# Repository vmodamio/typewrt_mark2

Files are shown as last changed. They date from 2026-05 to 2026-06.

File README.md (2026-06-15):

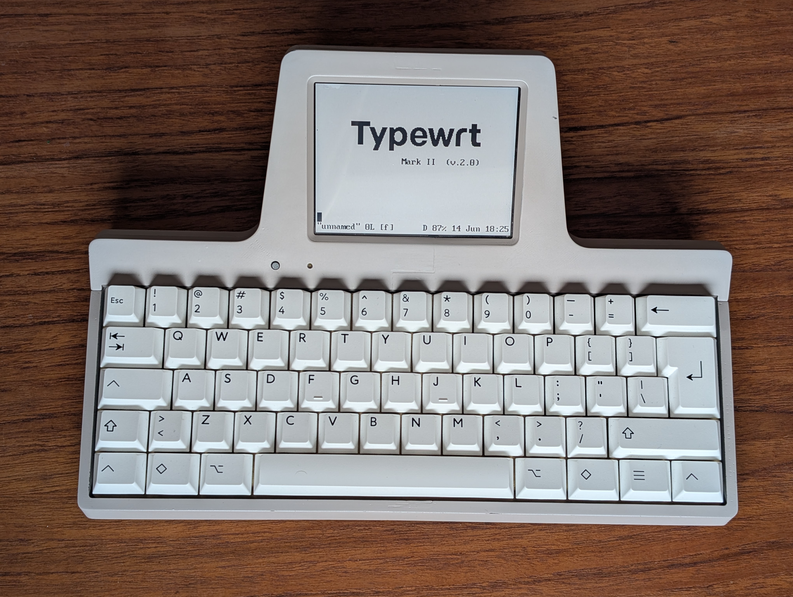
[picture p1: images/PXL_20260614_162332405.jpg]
Typewrt2


# Typewrt Mark II (ver 2.0)

Typewrt is a modern conception of a digital typewriter, designed as an
instrument for creating literary works without the need of further devices or
software. 
The idea revolves around a mechanical feeling, and it is designed with the
following key aspects:
1) Output: A reflective memory-in-pixel monochrome LCD from SHARP. This is a
4.4" display with a todays low resolution (320x240, QVGA). This resolution is 
enough to produce sharp glyphs using VGA font 8x16 bitmaps. It allows for 15
lines with 40 characters. The readability is exceptional both indoors and
outdoors. Because of the resolution and the ability to perform partial
refreshes, it updates very fast. 

2) Input: A mechanical keyboard with high quality switches and thick PBT
keycaps, arranged in a 60% layout. Mounted in a sturdy brass plate and a custom
made PCB. 
4) Power: Typewrt doesn't produce light. It doesn't stress the eyes. It doesn't
produce heat when you write on the lap. And it does not need a charger around.
The SHARP display is ultra low power. As it does the keyboard and the main
board. 
3) Process: The core of the device, and the main departure from a typewriter or 
a simple drafting device. Typewrt is an embedded vi text editor. It allows to
navigate through the document or documents very efficiently. Manipulate text
with any complexity, and recursively. Do search and replace, etc. You can even
autocomplete words, or perform fuzzy searches. It works natively with utf-8
encoding, and it can change the keyboard layout on the fly to english, spanish,
italian, french, german, norwegian, turkish and colemak.
5) Ergonomics: The design is meant to be robust and stable. The keyboard height
has been minimized. Cherry profile keycups are used, and the keyboard plane is
tilted by 6 degree.  The display distance and viewing angle is kept large
enough to allow long writing sessions. The display is 35 degree respect to the 
horizontal plane. The keyboard has been silenced as much as possible, so you
have a good peace of mind when typing in public places.  The tactility and
response of the keyboard is very conforting. 
6) Remote sync: The device has LE Bluetooth and allows to copy your files to
your phone consuming very little power, and without needing external networks.

The main difference of Typewrt mark II respect to the first iteration is the
hardware. Typewrt-I was built with a single-board-computer, running a ARM based 
linux from which you could run any program on the terminal. 
Typewrt-II doesn't have a computer. There is no terminal or specific drivers for
the keyboard or the display. Keyboard, display and text processor conform a
unique firmware embedded into a ESP32S3 microprocessor. 
Just one application (a modified vi editor with a simple file browser), running 
in a much more constrained environment. 8 MB of ram memory instead of 0.5 GB in
Typewrt-I. 1 MB firmware on flash memory instead of 0.5GB of linux distribution. 
And still, it performs faster, and consumes much less power. 
The interaction with Typewrt-2 is straight. There is no loggins or shells or
passwords. You press the power button and start writing instant on a blank 
document.

# How to:
Because the esp firmware is a submodule repository, clone this project as 
``` 
git clone --recurse-submodules https://github.com/vmodamio/typewrt_mark2.git 
```
The building process might be a long project. Please dont hesitate to ask if you
find difficulties and/or lack of documentation. 
For flashing the firmware, you need the Espressiff IDF installed in your computer.
You can follow [the instructions here for the v6.0](https://docs.espressif.com/projects/esp-idf/en/v6.0.1/esp32s3/get-started/index.html)
Once installed, from the /firmware/esp folder:
``` 
idf.py build
idf.py flash
```

# Firmware:
The text editor has been forked from the [fantastic nextVi](https://github.com/kyx0r/nextvi) 
text editor by Kyryl Melekhin. The editor, originally a terminal program, has been 
adapted to an embedded firmware using the Espressiff IDF, and it runs under FreeRTOS. 
Regarding functionality, the original right-to-left support, all the syntax highlight and 
filetype code, as well as all shell/terminal related code has been removed. 
The program has been adapted to a non-terminal environment, with a custom
keyboard and display interpretation. Additionally, all the functionality related to
files, paths or filesystem in general, has been derived to a more-dedicated filebrowser. 
The filebrowser is in fact the place where you land with the former quit command. 
A battery, memmory and date/time status has been added, as well as a BLE small protocol 
to transfer files.  And last, an special hard-wrap mechanism has been implemented.  

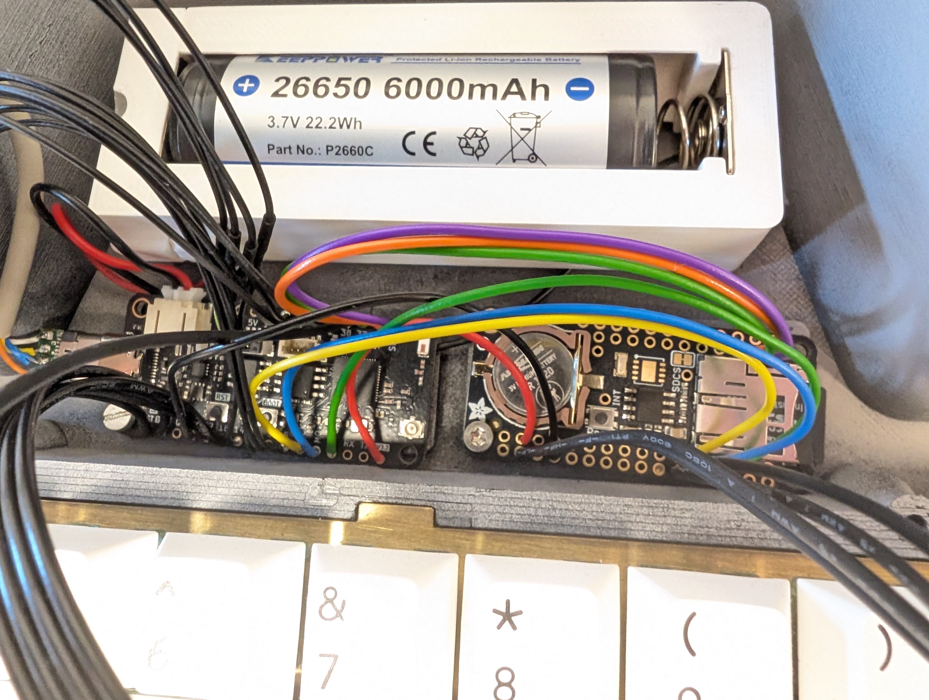
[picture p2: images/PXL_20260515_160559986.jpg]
hardware

# Hardware:
The machine consists on a feather ESP32s3[d] (unexpected maker) and an Adafruit
adalogger RTC+SD card. The Sharp MIP 4.4" display, is mounted in a custom PCB
that has a 5V booster, and a 7555 timer for the vcom signal (both ultra low
power). The keyboard pcb consists barely on an octal latch SN74HC573A that
drives 8 inputs/outputs. In addition, a power button and a yellow led on the 
enclosure, and a usb-c connector on the back. For the connector, a tiny pcb was
made to pull down the CC1 and CC2 lines with 5.1k. It has also a small jumper to
remove the data lines, in case you dont want someone touching your firmware. 

# Power figures:
Typewrt main display, the SHARP MIP, consumes 50 uA when idle, and 600 uA when
refreshing. It is probably the lowest power display ever. This, considering
that, in many writing divices, the display is by far the most power hungry part.
The keyboard on Typewrt mark I was implemented on a low power STM32
microcontroller, working in interrupt mode and sleeping most of the time, and
sending via uart events. Typewrt mark II is just one microcontroller, doing
exactly the same task as for the keyboard, but for the whole firmware. 
The display vcom signal is hardware produced with the timer, so no task is
needed for the display when the system is idle.
Check the power consumption folder for real measurements.
Machine idle is around 1.4 mA, typing costs 38 mA, and deep sleep 340 uA.

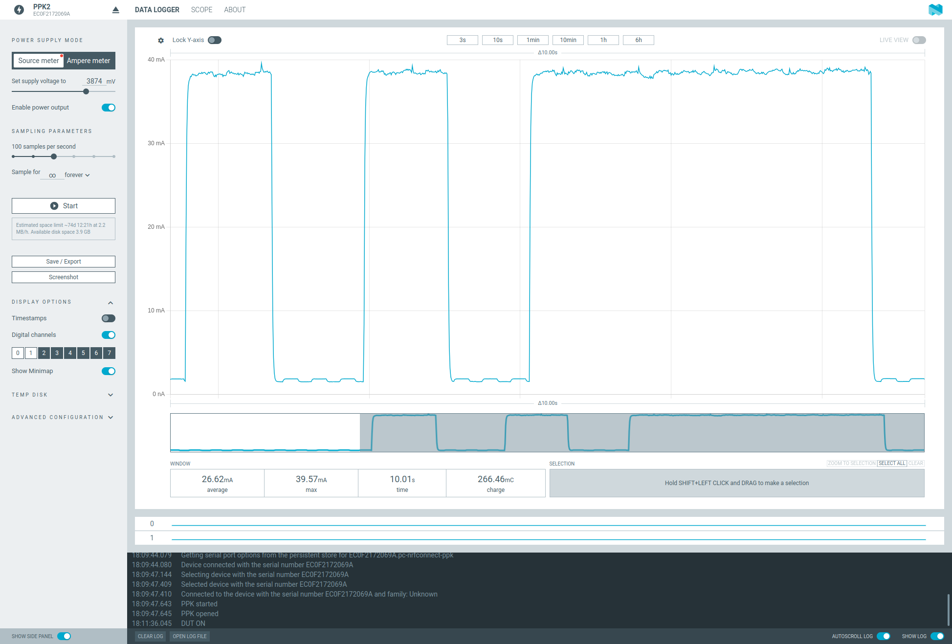
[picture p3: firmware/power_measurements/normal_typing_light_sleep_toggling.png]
power


# Vi at a glance:

Vi is one of the main text editors in unix/linux distributions. Its
functionality is divided into three different modes: insert, nomal and ex mode.
Once you are inside vi, you press "i" to enter insert mode, and you can start
typing in your document. Many people hate vi just because this initial
frustration, akwardness responses of the keyboard when you are not in Insert
mode. This is because vi is very powerful. It has many key bindings, and the
learning curve is somehow step. 

In insert mode, it behaves like the simplest text editor you could imagine. As
far as you dont escape, pressing the Esc key, you basically insert characters
in your text buffer. There are very few but useful key bindings in insert mode
however. Press Ctrl-W to delete your last word. Or Ctrl-N to autocomplete a
word you started typing.  To save your text (to write your buffer into a file),
you escape to enter normal mode, then you type ":" to enter ex mode, and "w
<filename>" to write.

Normal mode is where things get fun. In this mode you dont create text by
typing, but instead you type keybindings to manipulate the text you already
have, or navigate throw the buffer/buffers, copy or paste pieces of text into
the buffer, or different registers, search or replace, delete, and many other
things. This editor paradigm works very nice for coding, among other things,
were you would spend considerable part of your time rearranging pieces of text
or modifying functions or variables. For writing fiction I find it equally
useful.  The navigation, or movements, are the first step departing from your
standard, plain editor. The left, right, up and down cursor movements in vi are
arranged in the main keyboard row as h,j,k,l for left, down, up and right. 
That is the main reason you would't need arrow keys in a vi text editor. 
If you get used to this, you wont miss again the arrow keys.  You can move
forward or backwards by words, paragraphs, programmed marks, entire
documents/buffers.
You can concatenate actions with movements, like delete 5 words backwards, or
find character <character> 3 times, to say, or copy text til mark, or
paste register 1...  Pressing "." in normal mode executes the last instruction
again. For example "dB" to delete backwards  to the begining of a word
(including punctuation). Then pressing "." will continue to delete that way.

# Credits:
The text editor is based on the nextVI project (please refer to the firmware folder).
The VGA font is borrowed from the ZAP group, Australia (Copyright (C) 2004–26, John Zaitseff).
The font used for the splash screen is MomoTrustDisplay-Regular.ttf (Google fonts) 
designed by Type Associates, Copyright 2024 The MoMo Trust Display Project Authors. 

# License:
This project is distributed under GPL3 license. Copyright (C) 2026 Victor Modamio

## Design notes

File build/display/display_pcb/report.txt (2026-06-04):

Plotted to '/home/vik/typewriter/display/pcb/Sharp_display/Sharp_display-F_Cu.gbr'.
Plotted to '/home/vik/typewriter/display/pcb/Sharp_display/Sharp_display-B_Cu.gbr'.
Plotted to '/home/vik/typewriter/display/pcb/Sharp_display/Sharp_display-F_Paste.gbr'.
Plotted to '/home/vik/typewriter/display/pcb/Sharp_display/Sharp_display-B_Paste.gbr'.
Plotted to '/home/vik/typewriter/display/pcb/Sharp_display/Sharp_display-F_Silkscreen.gbr'.
Plotted to '/home/vik/typewriter/display/pcb/Sharp_display/Sharp_display-B_Silkscreen.gbr'.
Plotted to '/home/vik/typewriter/display/pcb/Sharp_display/Sharp_display-F_Mask.gbr'.
Plotted to '/home/vik/typewriter/display/pcb/Sharp_display/Sharp_display-B_Mask.gbr'.
Plotted to '/home/vik/typewriter/display/pcb/Sharp_display/Sharp_display-Edge_Cuts.gbr'.
Created Gerber job file '/home/vik/typewriter/display/pcb/Sharp_display/Sharp_display-job.gbrjob'.
Info: Done.

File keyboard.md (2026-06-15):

Typewrt keyboard is designed from scratch. From the pcb design to the driver
and communication protocol.  It cannot be called "driver" anymore since the
Mark II, as now everything is embedded in a unique firmware. But the concept
remains the same to my first Typewrt vision. In Typewrt 1, a interrupt driven
microcontroller was sending key events via uart, sleeping the rest of the time.
In typewrt 2, the whole firmware is in the same microcontroller, that is
globally sleeping when no key is pressed.

# Matrix and scaning mechanism:
The 60% ISO keyboard layout has 62 keys. The optimal way to arrange them would
be a 8x8 matrix, with only two spares.  Typewrt 2 has this matrix, and it
allowed me to use a very practical multiplexing mechanism to reduce even
further the number of pins used: an octal latch.  This is a small component
with 8 inputs and 8 outputs. You can program the outputs to be insolated
(latched), or to be seeing the inputs. The rows are connected to the outputs
and the columns to the inputs, so the mechanism goes as folow: you input one
high and rest low. This goes so far symmetrically to rows and cols, as the
output is connected to the input. Then you latch the outputs (insolated from
inputs now), and set the inputs...

# Debounce and denonise:
When a key is pressed, the switch contacts will bounce producing an intermitent
connection during few milliseconds, before it settles down. One standard
procedure for avoiding the misleading behaviour is to wait for a safe time
window, and read the status of the switch after. A typical debounce time is 10
to 20 ms. This delay is negligible and your keyboard is perceived as
instantaneous for you.  With this strategy however, the keyboard is not inmune
to noise in the circuit, that could trigger a false key event because of
residual charges in the line,for example. 
For typewrt 2 I opted for a robust debouncing/denoising strategy: using shift
registers.  The basic idea is that the status of a key is scanned several
times, every one millisecond. When te scan reports 8 consecutive and identical
states, that are different to the previous key status, it reports the key event
and changes the key status to the new value.This is maybe one of the pieces of
this project where I havent spare in power consumption, as it demands slightly
more cpu. But at the same time provides a very robust keyboard response, that
delivers key events as fast as possible.

# Keyboard autorepeat:
I have not implemented key autorepeat in Typewrt. That  means, you cannot hold
the backspace and continue deleting characters, for example. Autorepeat doesn't
introduce any important complexity, but I feel it somehow goes against the
philosophy of this machine.  First, without autorepeat I'm forced to delete or
manipulate text in the way vi is meant for. And second, it avoids high
refreshing rates for the display. Now, the Sharp display is quite fast
refreshing, but I wouldnt play finding the compromise between the fastest
backspace deleting speed and the limit this display could reach.  Seriously,
hitting the backspace to delete the last four or five words is highly
inefficient. The faster you would go, the more chances you wont even land in
the character you want. In vi you just press Ctrl-W and delete one full word at
once, with the cursor in the right place! or in normal mode you hit "dB" for
example, or "d5B" and  you delete 5 words at once. 

# Keyboard event:
This part might not be relevant at all for anyone. But it might serve useful
for understanding the potential of custom modifications for keymaps.  In a
normal keyboard, you wouldn't be able to program the caps-lock to perform
whatever you want, for example...  The keyboard events are 8bits. The MSB
indicates key pressed/released. The next bit is for indicating a modifier key.
When it is 0, the next 6 bits represent up to 64 possible physical switches in
the keyboard. When the 7th bit is 1 (modifier), the 6th bit represent
left/right, in case a modfier key is doubled (like Ctrl, or Alt), and the next
5 bit are mapped for Caps-lock, shift, Ctrl, Cmd and Alt modifiers.

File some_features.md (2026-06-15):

This machine is annoyingly fast. You dont have time to go prepare a coffee
while it boots.  Now, if you are in a rush to write down that wonderful idea
you got at midnight. Press the button  (if you left the machine off). You start
typing instant in your new document.  One feature (and I made it in purpose).
Execute the command :off, and the machine will dissapear from any powered form
instant. There is no prompt -Are you sure? y/N or something like this. You will
discard your drafts inmediatly. Here I assume you have the constant, and
healthy rutine of writing :w your ideas as they come.

# Help:
Try with ":help" for the embedded help. Use j,k to go down/up.

# USB charging:
Just plug any USB-C charger and continue. The machine doesnt reboot if you
connect the charger. It will however light the LED indicator to tell you are
powered by USB. One thing to note: because this feature, if the machine is off
and you decide to charge it, it will charge. But it wont show any light, nor it
will start the machine.

# LED indicator:
The led indicator remains off when you are on battery. But it will still notify with some blinking in some circumstances:
1) When the battery level is below 25% slow blinks every 5 min.
2) When the battery level is below 10% fast blinks every 1 min. Below 7% it will stop blinking, and instead it will popup a message overlay every 30s (that you dismiss on an keypress).
3) When writing to disk.
4) When transfering files via BLE.
5) Two little blinks when booting.

# The splash screen:
When you boot, a splash screen will appear, with the cursor parked at the
bottom. You have started a vi session, with a new file still "unnamed", in
normal mode. To start inserting text just press "i". The splash screen will
dissapear as you type. If you prefer to edit or view a previous file, just
press the menu key, or execute :menu.    

# Note on the power button:
The power button switches ON the machine. What it does is literally reseting
the board, that is essentially driven into deep sleep when powering off the
machine with the command :off (or pressing "P" within the menu).  In order to
prevent accidental resets, the button is dissabled when the machine is running,
and i wont do anything until you bring the machine off. This is done connecting
the switch to the reset pin and a dedicated gpio instead of the ground pin.
When the machine is on, that pin remains high, thus protecting the reset
action.  However, you can still reset while you are in the splash screen. I
left this possibility so I can flash firmware into the board during a fraction
of second, before the machine goes to light sleep and breaks the uart
connection with the usb. You can also play reseting the machine in the splash
to demostrate the booting speed.

# The menu:
The text editor nextVI had a powerful mechanism to list files on a buffer, and
some smart commands to open files also, acting all together as a small
filebrowser. This functionality was removed in favour of a more standalone
menu. The menu's purpose is to allow you list files, enter directories, and do
basic filesysem operations like delete, copy or rename. You can sort files by
date or size in reverse or normal order, or search for files.   
Additionally, the file row has a flag indicator to show wether it has been
synchronized with the phone since last modification (directories are
represented with [+] always). The flags are as follow:
1) \- indicates file not sync, neither marked to be sync (local copy only).
2) \* file marked for sync
3) s file is sync
4) x file is remotely deleted (only local copy).

If a file is remotely deleted, the local copy on the typewriter wont be deleted
when synching, but instead it will be marked as "x". This flag can be changed
again if marked for sync again.

Note on the file rows: there are two columns apart of the flag and file name.
The size and the date. Size is given in words, not in bytes. I found this more
useful. Date (last modification) is formated in a compact way. Similar to the
"-h" option when doing "ls" in a linux shell. It shows time if the mtime is
today. Shows day and month otherwise, if mtime is same year. Past years format
the mtime as dd/MM/YY.   When the file name is too long, it will be truncated
to the column. One can always pan with the 0/$ commands to see the head/tail of
the filename.  

Note on VI quit: In a terminal based vi editor, quiting would bring you to the
terminal. But Typewrt doesn't have terminal, it is just a vi editor. The
quitting commands used in vi, like :q or :wq for example, instead of quiting to
a terminal, they bring you to the menu browser. 

# Text editing and wrapping mechanism
There is an important difference between the original nextVI and this
implementation. The line wrapping.    Because of the small size of the screen,
and the purpose of this machine (writing, not coding), a hard-wrap mechanism is
always active. When you type a long line, the text will flow to the next line,
producing a real line-break in the text file. This is different from the
soft-wrapping in which the line splitting is only visual, while the text
written on file still a very long line.  This decission soft/hard has been a
tough one. Originally I was inclined to the soft wrapping. But that continuos
reformatting of text comes heavy in the cpu. Even scrolling text demands
another reformatting of the lines as they appear on the screen.  There are few
uncomfortable aspects of the hard wrapping however. If you open the text in
another device, it will show the text formatted to 40 col width. Exactly the
same as you see here. This I decided to survive with, as the Typewrt was meant
from start to be a standalone editor/processor, and the text wouldn't need that
much work on a different device. The second aspect was more anoying. If you
decide to insert or remove text in the middle of a hard wrapped line, all the
line-breaks inserted by the mechanism would play against you. You will end up
with many ugly, short chunks of text spreaded over several lines.  To keep it
sleek, I decided to implement my own hard-wrapping mechanism.  The machine now
differenciates between a line break inserted by you (when you hit enter) and a
line break forced by the wrapping mechanism. This is done by adding a hidden,
zero-width character besides the line-break character.   When you modify the
content of a previous line, the wrapping mechanism will reformat the line, but
removing those old, forced line-breaks before, so the text will flow gracefuly
again after you escape.  I find this very rewarding, because the text is kept
tidy with very little cpu processing.   

# Keymap and language:
The nextVI editor is very powerful. It allows to change between keyboard
layouts on the fly. I introduced more keymaps and mapped to a dedicated key in
the keyboard, the Alt key. Pressing Alt-e would change to english, Alt-s to
spanish, etc. Pressing Alt-space pops a helper showing the current layout, so
you can find those characters you dont remember.   \ Note on the keyboard: The
keyboard has been fully reimplemented for this machine. Compared to the
original code, Typewrt doesn't run on a terminal at the end of the day. Nor it
has a standard keyboard event handler (it is fully new). The keyboard layout
works mostly with only two layers: normal, and shift (plus dead keys depending
on the language). That means that some characters in some languages, those
accessed with Alt-, are missing. Fortunately those are mostly standard symbols
or parenthesis/brackets, that are very easily accesible throw the english
keyboard.  

Notes on VI editor:  One thing to note is that the language layout affects
mostly to the insert mode, while the normal mode works with the US layout. That
is done in purpose, for muscle-memory of the commands.   

# VI related keys on keyboard:
The Typewrt has a 60% keyboard layout, with 62 keys. On the bottom row it has
the space, Ctrl, Alt and two other types of key: the Cmd key (left and right)
and the Sys/Menu key (on the right). They Sys key brings you to the menu. The
Cmd key has several purposes depending on which VI mode are you. In insert
mode, it lets you parse a normal mode command, returning to the insert mode
after. Think on, "gg" for going to line 0, or "0" to go to start of line...when
you need a quick navigation instruction without leaving insert mode, or you
need to delete some words or lines quick. In normal mode, it just scrolls. Same
as Ctrl-F , but keeping the curor line constant. Also, Ctrl-Cmd scrolls the
other way. 

# Buffers and simultaneously open files:

In VI, a open file is stored in a buffer, that you manipulate. The file doesn't
change until you write the buffer. This buffers are nothing special to VI, as
all text editors work with the same principle. The importance of the word
"buffer" in VI comes with the way you interact with the buffers. You can copy
between them, navigate between them. The copied text can be send to a buffer.
Typewrt has a very limited ram and therefore a special care has been taken when
opening buffers or manipulating them. When the system pass some memory
threshold, it will eventually close buffers that are not modified. It will also
prevent you to open new files into buffer over some quote of memory used.  

# Global marks:

In VI, and nextVI, a very useful feature is the mark. You can tag a cursor
position with a mark flag, a letter. You do so in normal mode pressing
"m+<letter>". At any point you can navigate to that mark pressing
'<letter>Alphabetical marks are buffer-wise. Numerical marks are global, so you
can navigate to that position, in that file, from another file.  In Typewrt the
global marks are persistent. So if you switch on the machine, you can still
navigate to that position in that file, provided you remember the marks you
did. If you dont remember, the command :gmarks prints a list of the marks, and
let you chose one to go to.  

# Notable VI feautures worth mentioning:
Autocompletion, registers, marks, global marks, visual mode. Just play with this.

# Note on the display font:
The Sharp display is amazingly simple to drive. There are just two mainly
primitives: clear, and write. Because displaying a bitmap font is not worth
using a entire library. I just created the few functions I would use as a small
API: writing a line of text, clear the display, and rendering some graphics.
Clear display is one single instruction. The graphics is simply writing the
corresponding lines, everithing at pixel level.  The only interesting part is
the character rendering. For that, a bitmap font is just rendered. Because the
font is a VGA 8x16, 16 lines of the display need to be refreshed everytime a
character appears. This is because the Sharp partial refresh is line-wise.  The
bitmaps for the font glyphs have been stored bit-reversed, because the spi
protocol writes pixels from left to right, while the font bitmaps contain the
gliphs from LSB to MSB. This saves some redundant processing. 

# The font:
I found this font extremely pleasant. It is based in the original VGA font from
IBM (I guess), but slightly reformulated and extended by the ZAP group
Australia.  They have put lot of attention in some characters. Also, the
version used here, with 256 glyphs, covers almost all the european languages.
This group has released as well a 512 character set. But I found this 256 good
enough for my language spectrum.
The font is solid, bold, and renders very nicely. They have created also a
light, modern font. But I still prefer the readability of this one.

# Wireless communication:
The ESP32s3 comes with both wifi and bluetooth. The reason I chose BLE for
remote transfers is power consumption, memory used in the stack and in the
flash, and also because of the avalaibility.  Wifi consumes way more power, and
have way more overhead. But its transmission is much faster. This means that,
from some transfer size up, wifi becomes favorable. The estimate would be
around 0.5 MB. But this would only be favorable if you perform a single
transfer.  If you were transmitting periodically, the time spent with the
antenna on wont be that favorable any longer.  Apart of the power, BLE allows
you to transfer your data to your phone withoutincurring in a public or private
network. You dont need to rely on the wifi signal. The transfer is just between
Typewrt and your phone, with no intermediates. And I love that feature.

# SD card and RTC:
There is a small, feather format, extra board which consists on a RTC and a
micro SD card slot. It is called Adafruit adalogger, and it suits Typewrt2
perfectly. The RTC keeps time and date with an coin cell, and the SD cards is
basically the storage for the mahine.  Regading the SD. Many people would
probably like a slot in the enclosure, so one can extract the card and copy
files. My modern laptop doesnt have SD card slot. I decided to buy a efficient
card reader to transfer photos from my digital camera (beware, bad quality ones
get very hot). The modern version of my camera now transfers all the photos via
wifi!  Somehow I though, the less te card is extracted and inserted, the
better. I want the SD card to seat fixed in the body and act as a hard drive,
with the less possibles chances to fail.  The reason I chose a SD card slot
instead of a soldered EMMC solution is another one: SD cards consume much less
power! they have internal sleep modes, and require less pins as well. Of
course, the SD card writing/reading speeds are much slower than EMMCs, and
that's totally fine for a typewriter who deals with small text files and no
high resolution photos or videos.

For the SD card, I chose an industrial APT single cell card. They are extremely
expensive and come with much less memory, but they are the toughest and more
reliable cards. For the price of a good quality Samsung 64GB, I got this single
cell card with 512 MB. I just loved it.

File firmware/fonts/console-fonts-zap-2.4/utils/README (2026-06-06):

.. -*- mode: rst; coding: utf-8 -*-
.. role:: filename(literal)
.. default-role:: filename

============================
Linux Console Font Utilities
============================

The Linux Console Font Utilities package contains various applications to
manipulate Linux console fonts.  In particular, programs are included to
convert standard PSF font files to a text representation and vice versa,
allowing easy font editing using any text editor.

The following programs are included:

* ``psf2psftx``         — Convert binary PSF font to text representation
* ``psftx2psf``         — Convert PSFTX text representation to binary format
* ``freebsdvfnt2psftx`` — Convert FreeBSD VFNT font to text representation
* ``psftx2freebsdvfnt`` — Convert PSFTX representation to FreeBSD VFNT font
* ``rawfnt2psftx``      — Convert raw font file to text representation

* ``psftx-codechart``   — Generate a PDF font coverage codechart
* ``psftx-encodings``   — Check PSFTX for charmap encodings coverage
* ``psftx-sampler``     — Generate a text output font coverage sampler
* ``psftx-screenshot``  — Generate a simulated screenshot image
* ``psftx-template``    — Create a blank template PSFTX file

The following Python modules are included:

* `psffont.py`          — Object-oriented interface to in-memory PSF font
* `psfio.py`            — Input/output functions for binary PSF files
* `psftxio.py`          — Input/output functions for PSFTX text files
* `freebsdvfntio.py`    — Input/output functions for FreeBSD VFNT files
* `rawfntio.py`         — Input/output functions for raw font files
* `unicustom.py`        — Custom Unicode mapping functions

The following additional libraries are required for correct operation:

* reportlab     — Create PDF documents (required for ``psftx-codechart``)
* Pillow PIL    — Python imaging library (required for ``psftx-screenshot``)

Feedback
========

Your comments, suggestions, corrections and enhancements are always
warmly welcomed!  Please send these to:

    :Postal:  | John Zaitseff,
              | The ZAP Group Australia,
              | Unit 6, 116 Woodburn Road,
              | Berala, NSW, 2141,
              | Australia
    :Email:   | J.Zaitseff@zap.org.au
    :Web:     | https://www.zap.org.au/projects/console-fonts-utils/
    :FTP:     | https://ftp.zap.org.au/pub/fonts/console-fonts-utils/
              | ftp://ftp.zap.org.au/pub/fonts/console-fonts-utils/
    :Git:     | https://www.zap.org.au/git-browser/console-fonts-utils.git
              | https://git.zap.org.au/git/console-fonts-utils.git
              | git://git.zap.org.au/data/git/console-fonts-utils.git

Copyright
=========

**Copyright © 2004–24, John Zaitseff**

The Linux Console Font Utilities package is free software that is
distributed under the terms of the GNU General Public License.  You can
redistribute it and/or modify it under the terms of that License as
published by the Free Software Foundation, either version 3 or (at your
option) any later version.

This software is distributed in the hope that it will be useful, but
WITHOUT ANY WARRANTY; without even the implied warranty of
MERCHANTABILITY or FITNESS FOR A PARTICULAR PURPOSE.  See the GNU General
Public License in the file `COPYING` for more details.

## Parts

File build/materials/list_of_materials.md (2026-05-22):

# Detailed list of materials:
  This is the list for all the components in the buid. It does not contain the
specific components for the PCBs (described in the respective folders), nor the
extra material for the building process (solder wire, flux, sand paper or glue
for the enclosure finish). Some makes like the switches, stabs, keycaps, SD
card, or the keyboard plate material, paint, etc, are just mention for
completeness of the project (feel free to pick your own).

## Display
* Sharp MIP LS044Q7DH01 : 4.4" reflective LCD, SPI protocol with 3.3V logic and
  5.0V power. It does partial refreshes with 1 line granularity. 
* Display PCB : custom made PCB for the Sharp display. It basically exposes the
  MOSI, SCLK and CS pins from the display, links the enable pin to the 3.3V
  input (note that the 3.3V is provided from the secondary LDO2 in the ESP
  board, that can be switched on/off), provides the 5V from the 3.3V with an
  efficient booster, and provides the VCOM signal via an ultra low power timer.
  Materials for the PCB are listed in the PCB folder.
* PC 0.7mm screen protector.

## Keyboard
* Laser cut bronze keyboard plate.
* Switches x62 MX cherry style (Durock silent Shrimp T1, custom lubbed)
* Stabilizers (Durock), pcb mounted, 1.6mm pcb gap.
* Switches foam (between plate and pcb).
* keyboard PCB : arranged the switches in a 8x8 matrix, all switches with 
  diodes, and an octal latch as the only component. Materials for the PCB are
  listed in the PCB folder. 
* Keycaps for MX cherry compatible (PBTFans doble shoot 1.6mm thick)

## Cables

## Hardware
* Feather S3[d] from Unexpected Maker (esp32s3 with 16Mb Flash and 8Mb PSRAM)
* Adafruit adalogger featherwing: RTC with coin cell and SD card slot.
* SD card : ATP 512 Mb (industrial grade, SLC) FAT32 formatted.
* Antenna : Optional (there is space under the display lid to glue one). The
  feather board has both a small antenna and connector for external one.

## Battery
* LiIon 26650 with protection circuit (they are slightly longer, even though the
  design has margin for 5mm difference) : 6000 mAh.

## Enclosure
* Main body, splitted in two parts for 3d printing.
* Display lid, splitted in two parts for 3d printing.
* Display clamps x2, to hold the pcb to the lid.
* Battery holder-container.
* Battery holder-lid.
* Battery contacts, negative and positive.
* Screws: all M2.5. 2x12mm, 5x16mm, 2x5mm and 2x5mm flat head, conical for the
  USB connector.
* Inserts: for M2.5, 3.9mm diameter, 4mm height, 9x.
* Paint, filler and primer : acrylic spray paint. 
* Rubber pads : adhesive, 3M, 10mm diameter, 1mm thick.

## USB connector
* Amphenol USB-C right angle rugged.
* USB PCB : a small breakboard for the connector, exposing the power, gnd, and
  data lines to the board, and pulling down with 5.1k resistors the CC1 and CC2
  lines upstream. It has also a small jumper to cut the dat lines, in case you 
  want to avoid any accident breaking the firmware of the typewriter when
  connecting the USB. Note that the machine is meant to transfer files wireless
  anyhow, and it doesnt grant access to your SD card with the USB.   
* USB-C male connector breakboard, to mate the board with the enclosure
  connector (see also the cables section).

## Led indicator
* Kingbright 1.8mm L-2060YD yellow
* current limiter resistor 320 Ohm

## Power button
* Omrom sealed tactile switch. 8x8mm B3WN.

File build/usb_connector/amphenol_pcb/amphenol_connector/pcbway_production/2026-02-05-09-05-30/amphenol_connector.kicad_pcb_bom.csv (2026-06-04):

Designator | Quantity | Value | Footprint | Package | MPN | DNP | Mount_Type | PARTREV | STANDARD | MAXIMUM_PACKAGE_HEIGHT | MANUFACTURER | Description
J1 | 1 | MUSBRM1C1M0 | AMPHENOL_MUSBRM1C1M0_no_courtyard |  |  |  | tht | D | Manufacturer Recommendation | 9.05mm | Amphenol
J2 | 1 | Conn_01x04_Pin | PinHeader_1x04_P1.27mm_Vertical |  |  |  | tht |  |  |  |  | Generic connector, single row, 01x04, script generated
JP1 | 1 | Jumper_2_Open | PinHeader_1x02_P1.27mm_Vertical |  |  |  | tht |  |  |  |  | Jumper, 2-pole, open
R1, R2 | 2 | 5k7 | R_1206_3216Metric_Pad1.30x1.75mm_HandSolder |  |  |  | smt |  |  |  |  | Resistor

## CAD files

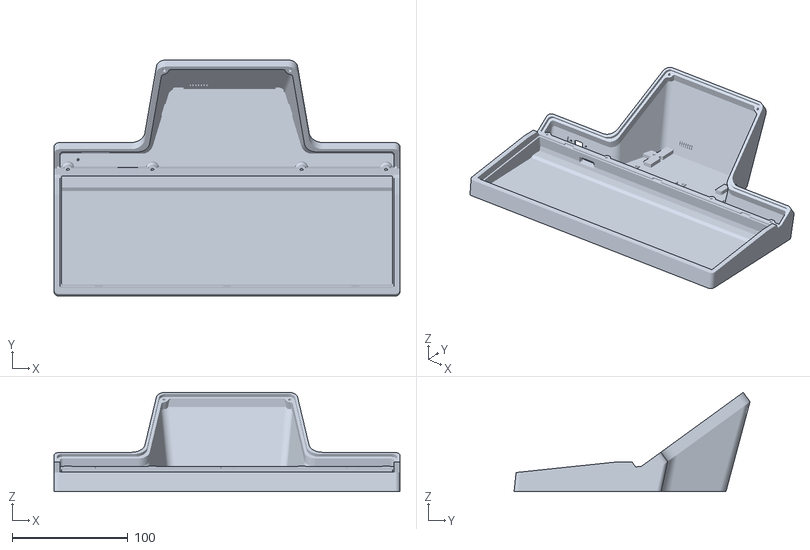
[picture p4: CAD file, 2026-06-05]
build/enclosure/typewrt2_body_full.stl
298.8 x 203.7 x 85.7

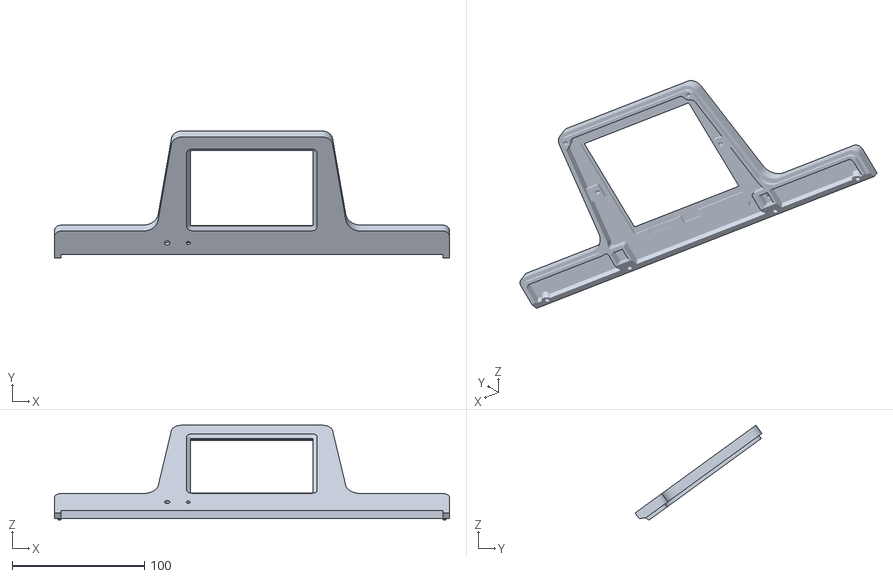
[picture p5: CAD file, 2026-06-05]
build/enclosure/typewrt2_display_lid_full.stl
298.8 x 95.9 x 71.6

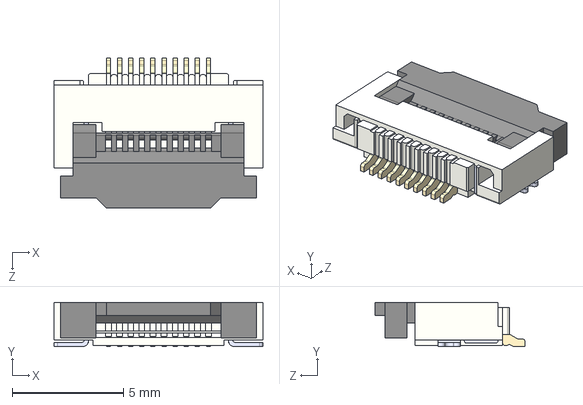
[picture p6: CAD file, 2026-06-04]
build/display/display_pcb/FFC2B35-10-G_REVA2.step
9.40 x 2.00 x 6.76 mm

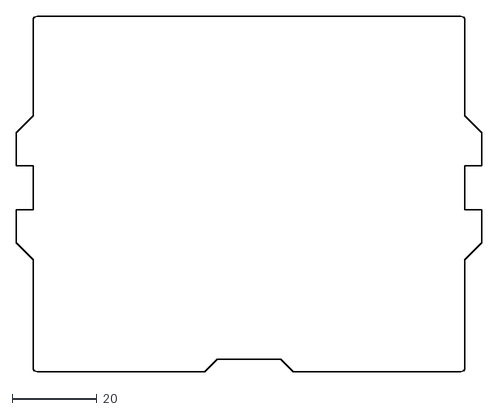
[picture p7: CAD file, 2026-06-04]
build/display/display_pcb/gerbers/Sharp_display-Edge_Cuts.dxf
110.0 x 84.0

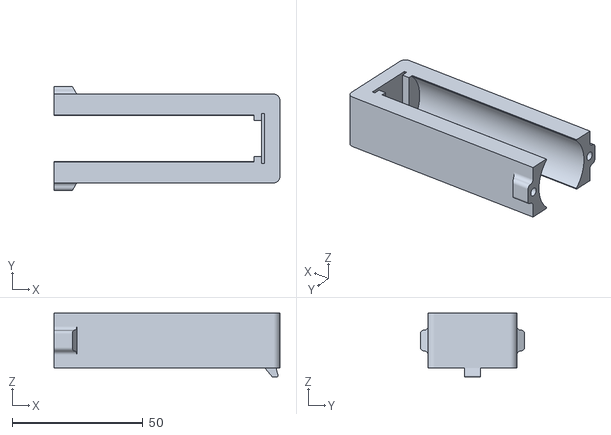
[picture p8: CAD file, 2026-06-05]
build/enclosure/typewrt2_battery_carrier.stl
86.6 x 40.0 x 24.4

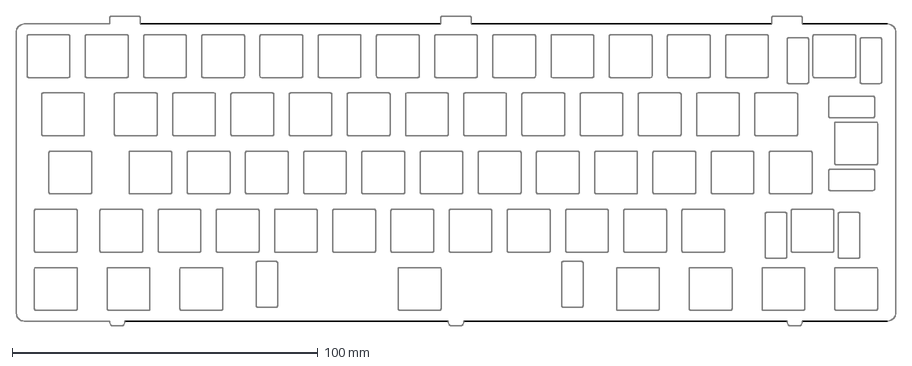
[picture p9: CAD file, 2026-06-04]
build/keyboard/keyboard_plate/typewrt_V2_plate_only.dxf
287.8 x 101.3 mm

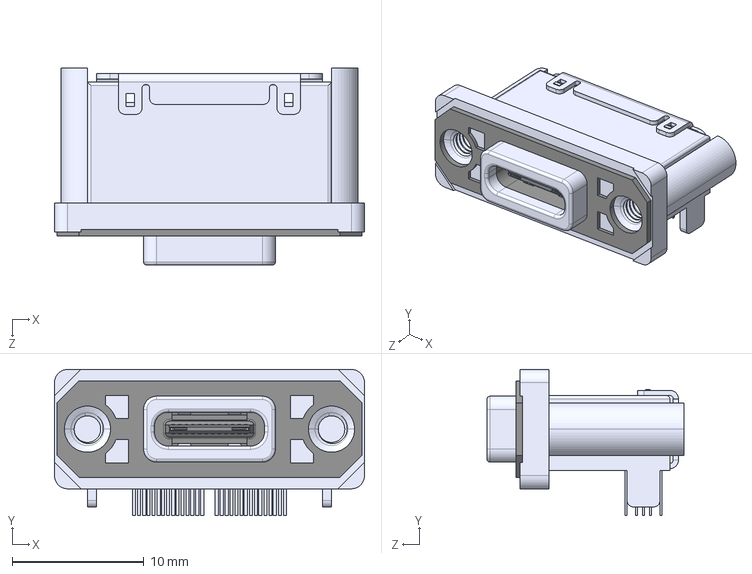
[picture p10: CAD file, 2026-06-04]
build/usb_connector/MUSBRM1C1M0.step
23.5 x 11.1 x 14.9 mm

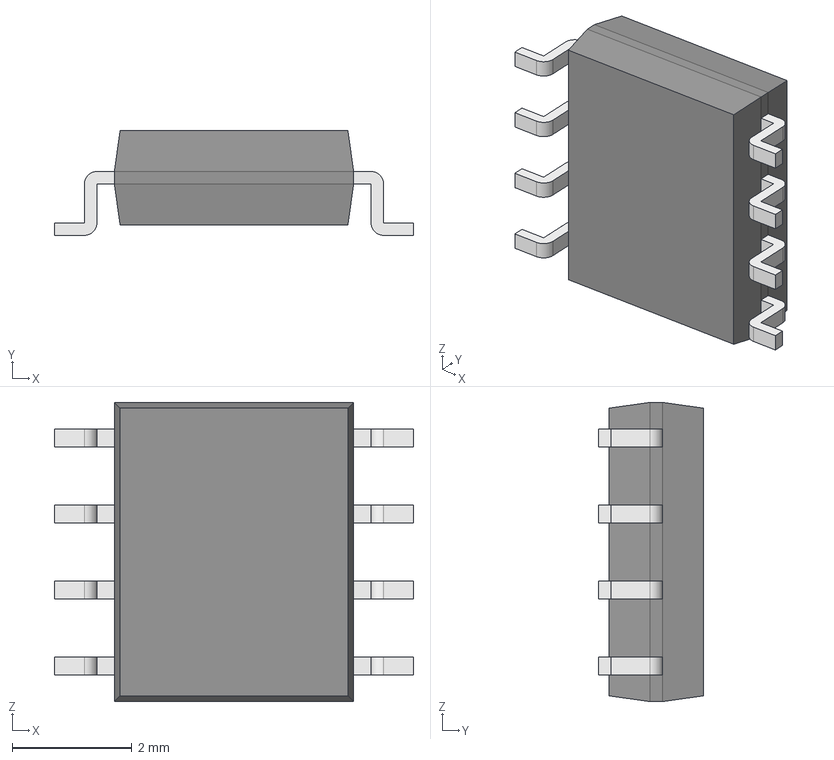
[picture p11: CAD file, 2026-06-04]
build/display/display_pcb/ICM7555IBAZ.step
6.00 x 1.75 x 5.00 mm
Body001 (Mirror #1) x 4
XY-plane x 12
X-axis x 12

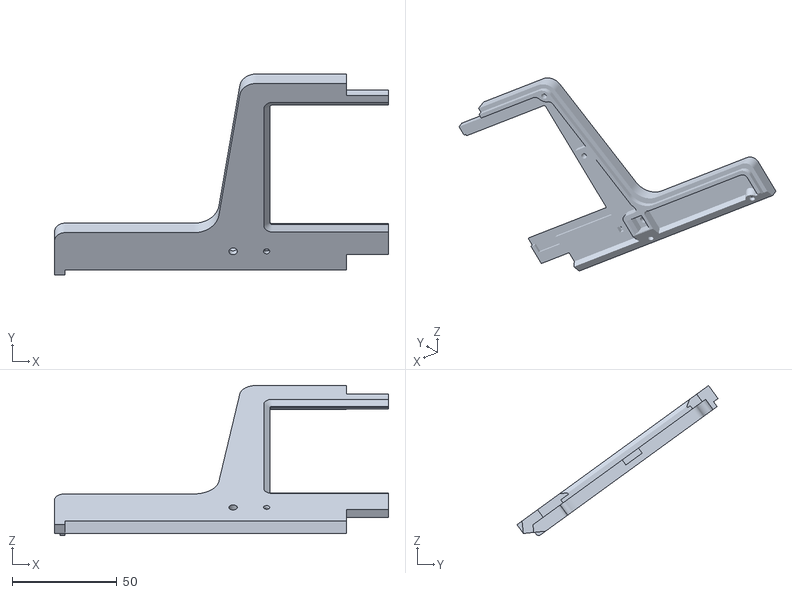
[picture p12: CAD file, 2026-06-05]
build/enclosure/typewrt2_display_lid_left.stl
159.4 x 95.9 x 71.6

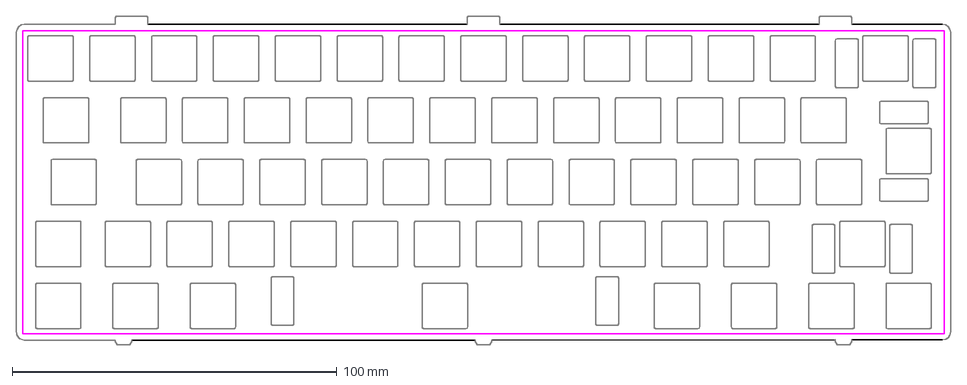
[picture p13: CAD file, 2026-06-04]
build/keyboard/keyboard_plate/typewrt_V2_plate.dxf
287.8 x 101.3 mm

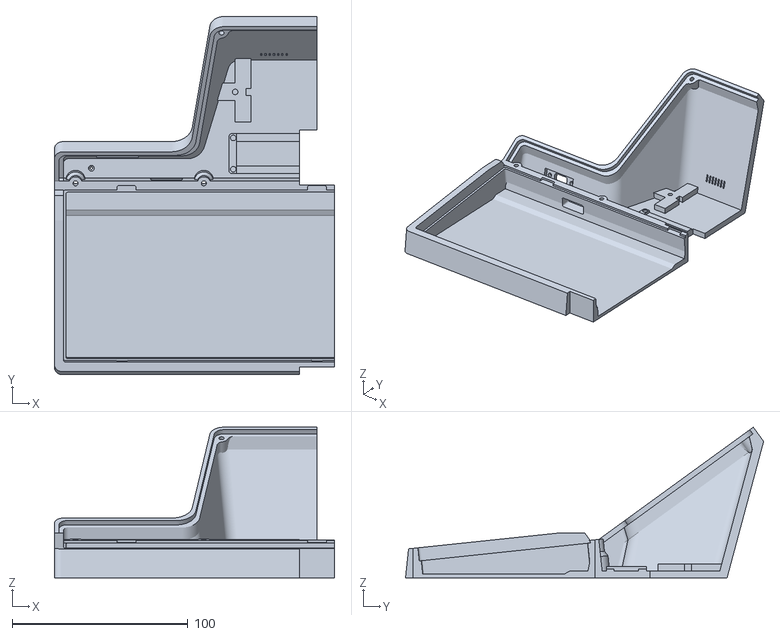
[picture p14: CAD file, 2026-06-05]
build/enclosure/typewrt2_body_left.stl
159.4 x 203.7 x 85.7

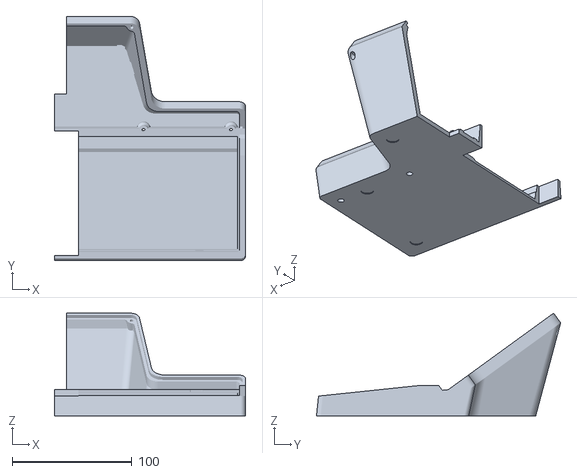
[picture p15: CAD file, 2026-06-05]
build/enclosure/typewrt2_body_right.stl
159.4 x 203.7 x 85.7

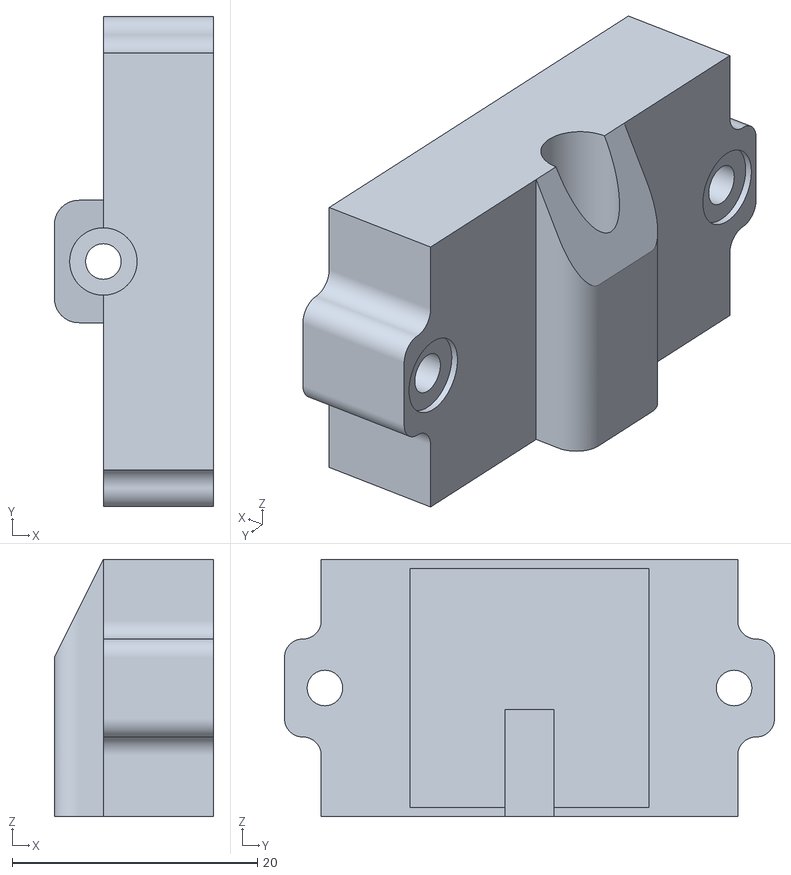
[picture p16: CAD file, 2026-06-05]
build/enclosure/typewrt2_battery_head.stl
13.0 x 40.0 x 21.0

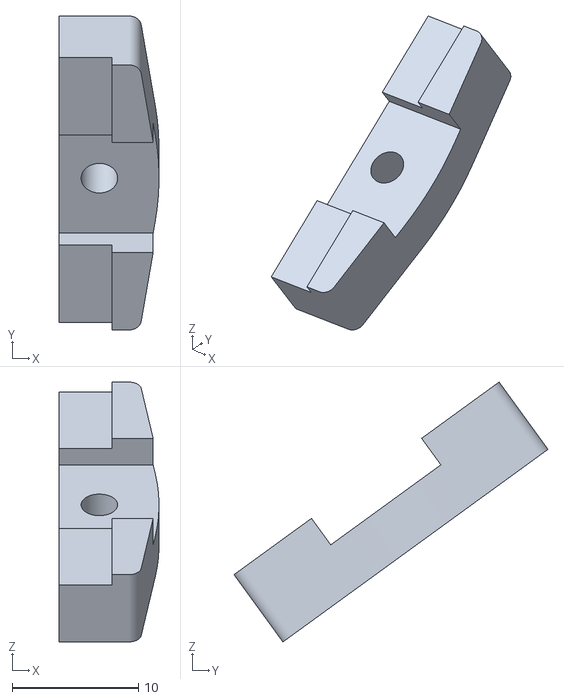
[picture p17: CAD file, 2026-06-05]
build/enclosure/typewrt2_display_clamp.stl
7.93 x 24.9 x 20.6

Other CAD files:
build/enclosure/typewrt2_display_lid_right.stl
build/display/display_pcb/gerbers/Sharp_display-B_Silkscreen.dxf

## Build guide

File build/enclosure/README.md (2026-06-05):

# Enclosure

The enclosure has been designed with Onshape, a cloud based
cad system that is free of use (as far as you keep public 
your project). 
This enclosure's project is named: 

typeV2-third-battery-new_ventilation

And you can access the project and make modifications at your 
convenience. 

## Body
The main enclosure has two pieces: body and display-lid. 
There are also splitted versions (with notation left-right) in
case your printer bed size is smaller.

## Batery
The battery is hold with a small case: carrier and head. You 
should insert the battery negative contact in the carrier slit, 
and glue the battery positive contact in the head.

## Display
The display pcb is held on the lid with two clamps, that are 
screwed in the enclosure. 
There is space to insert the pcb (that holds the display with
double side tape) and also a thin acrylic sheet (from 0.25 to 
0.8 mm thickness).

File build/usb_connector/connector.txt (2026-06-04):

GlobTek JACK-USBC-6STM-2SL
Super easy and small, with flange mounting....
Only thing is: the 6 pins are redundant 3: GND, VCC and CC
So no data lines!!
That could actually be positive, so no one could just plug the 
machine and start messing with the system.
Only problem is that, to program it, I would need to 
disassemble the lid and conenct a proper USB cable.

NOTE: The connector has eff. 3 pins. VDD, GND and CC. 
But the other end connector( to the board) would probably
have 4 connectors: VDD, GND, and D+ D-, with a small 
resistor for the CC lines....

So basically, if the connector to the board is having already the 
CC resistors in place, I would only need to connect two 
cables: VCC and GND.

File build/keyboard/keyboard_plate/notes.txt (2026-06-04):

Here a online generator for plate, and switches footprints...

https://ai03.com/designer-resources/

https://kbplate.ai03.com/

The stabilizer for the spacebar is rotated 180.

https://www.keyboard-layout-editor.com/#/

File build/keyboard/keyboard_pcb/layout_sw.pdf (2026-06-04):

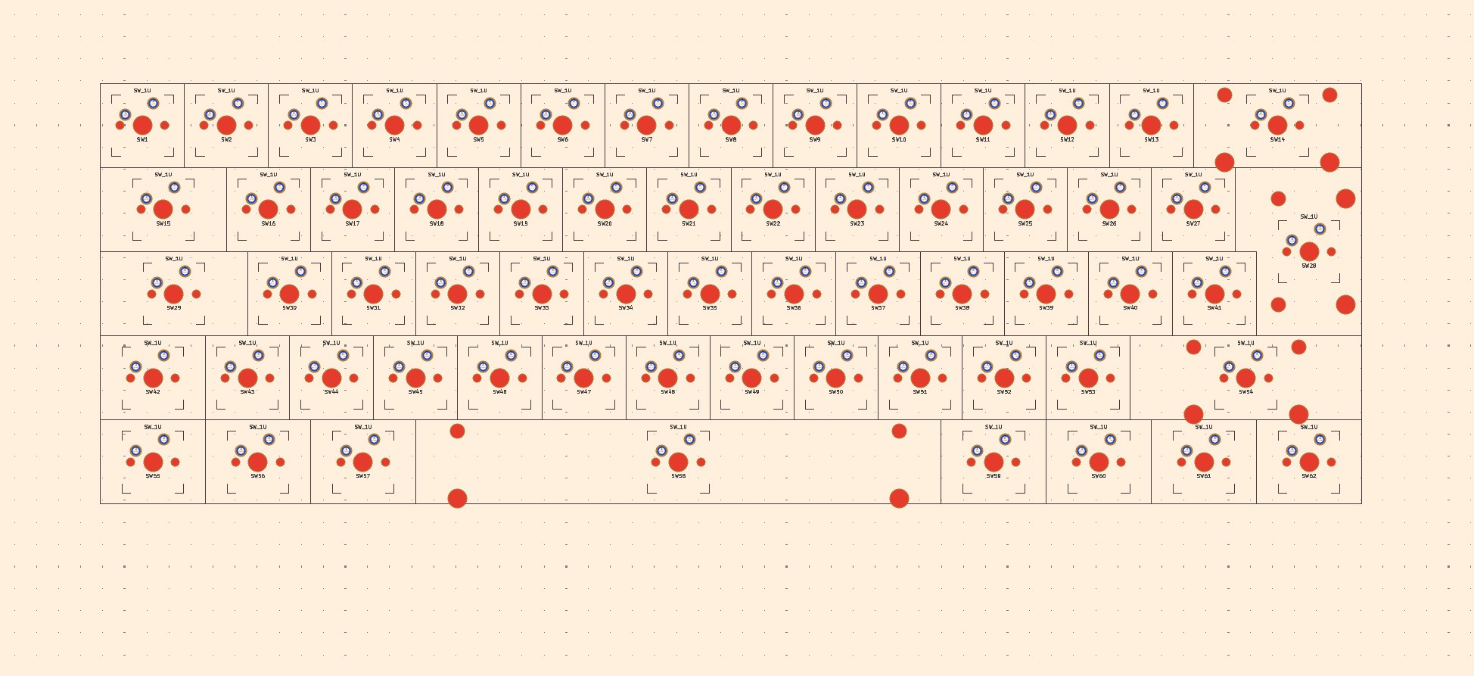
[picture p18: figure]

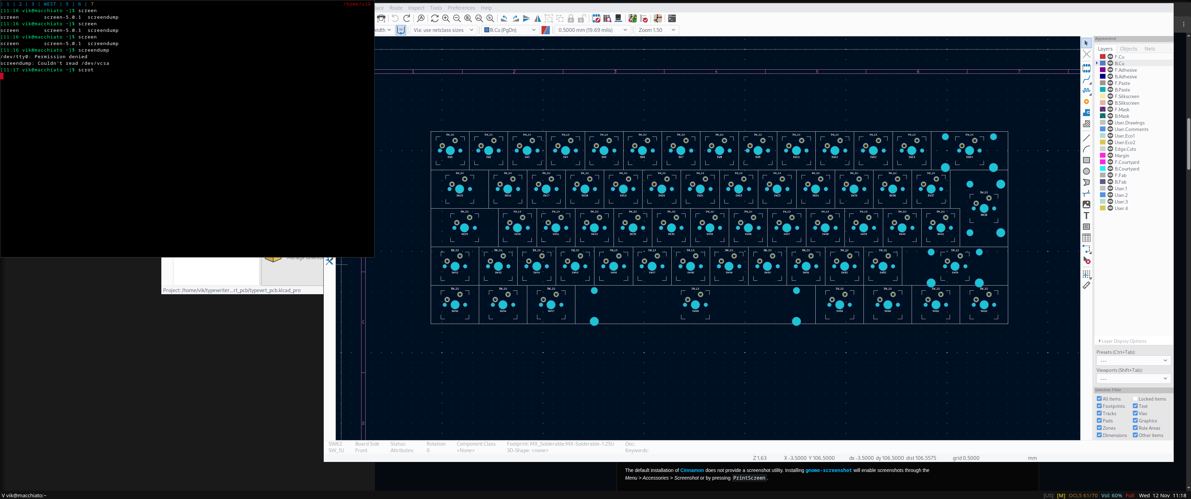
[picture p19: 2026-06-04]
build/keyboard/keyboard_pcb/2025-11-12-111806_3440x1440_scrot.png

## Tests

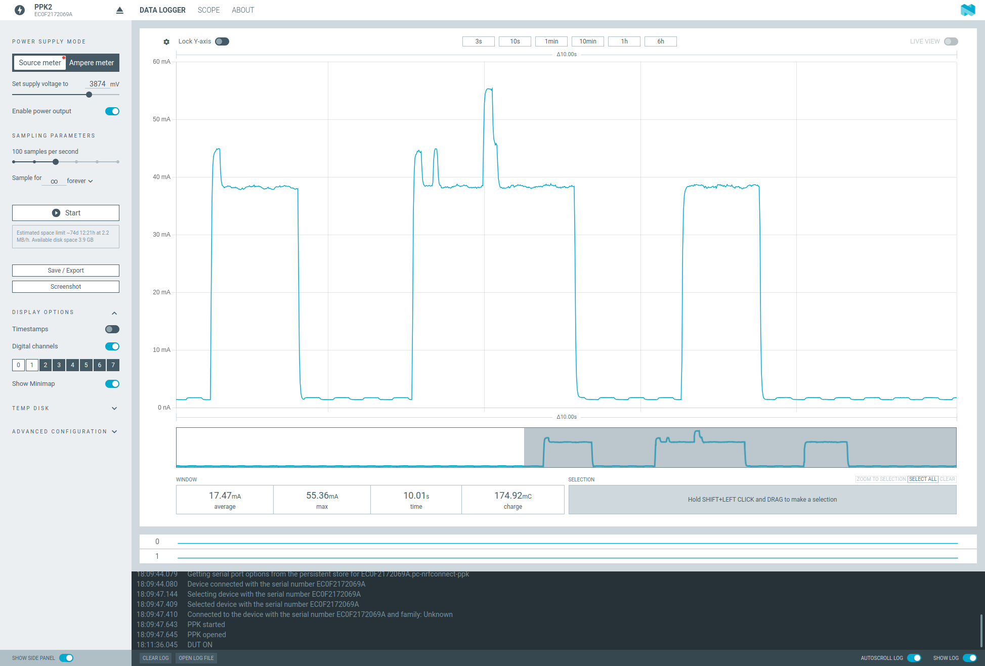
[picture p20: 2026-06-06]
firmware/power_measurements/writing_to_sd_card_spike.png

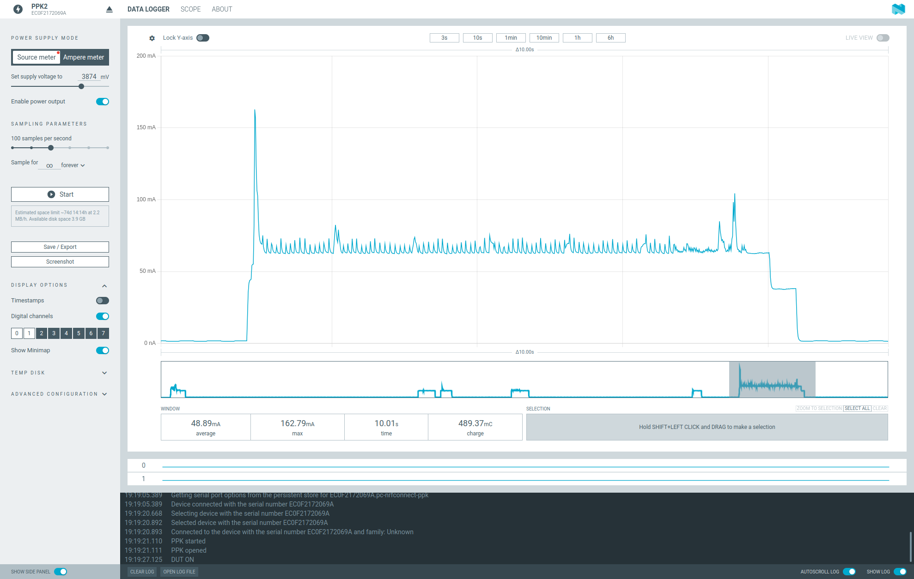
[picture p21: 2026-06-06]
firmware/power_measurements/ble_typewrt_sending.png

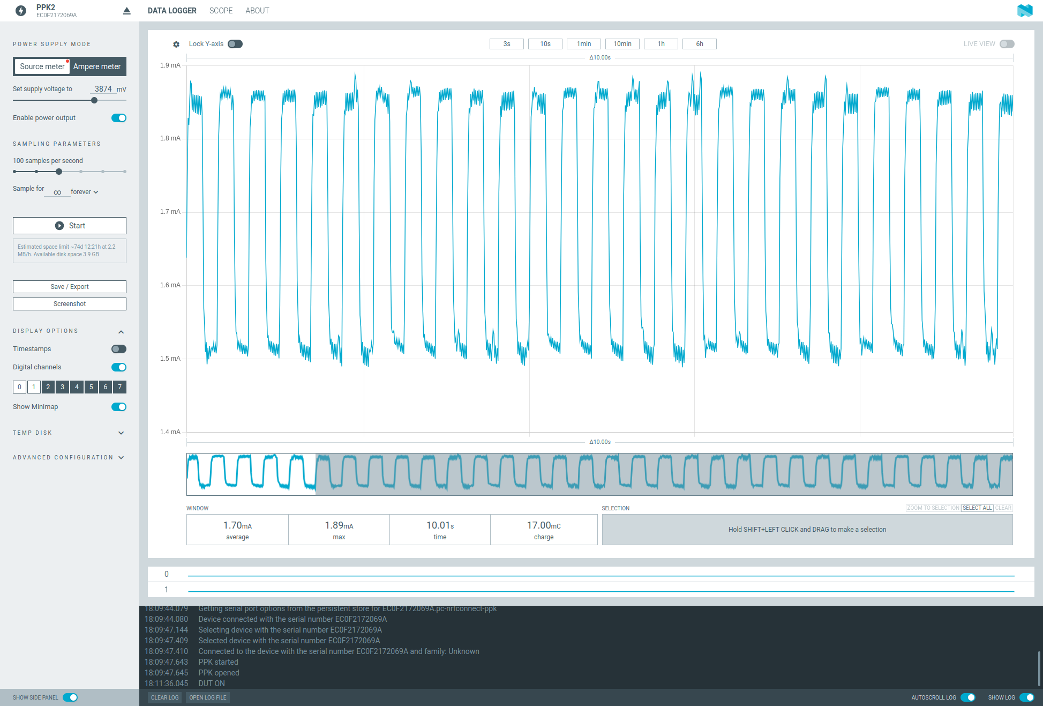
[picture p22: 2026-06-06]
firmware/power_measurements/light_sleep_display_toggling.png

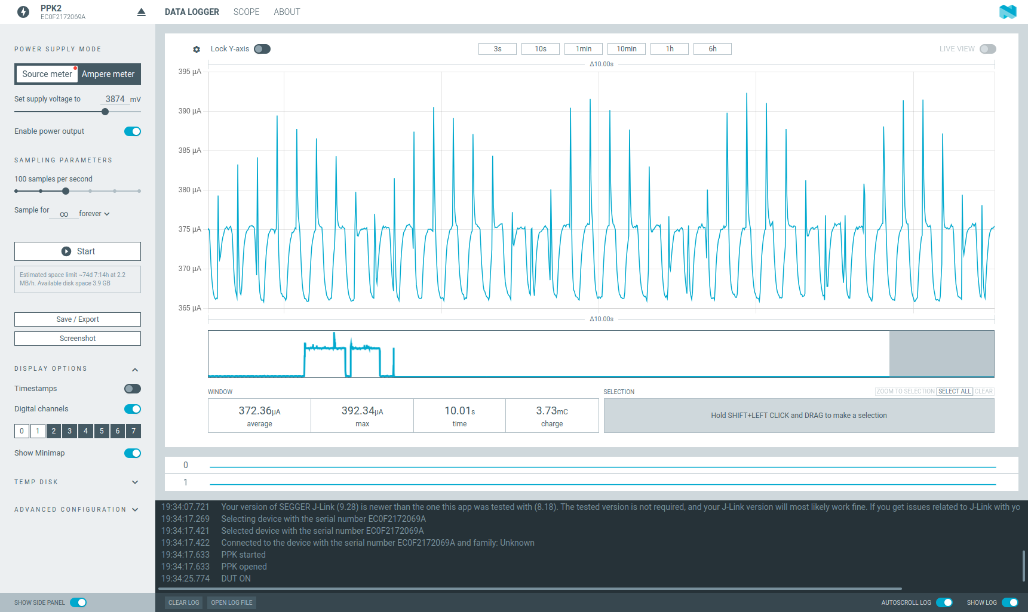
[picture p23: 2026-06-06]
firmware/power_measurements/deep_sleep_after_tweak.png

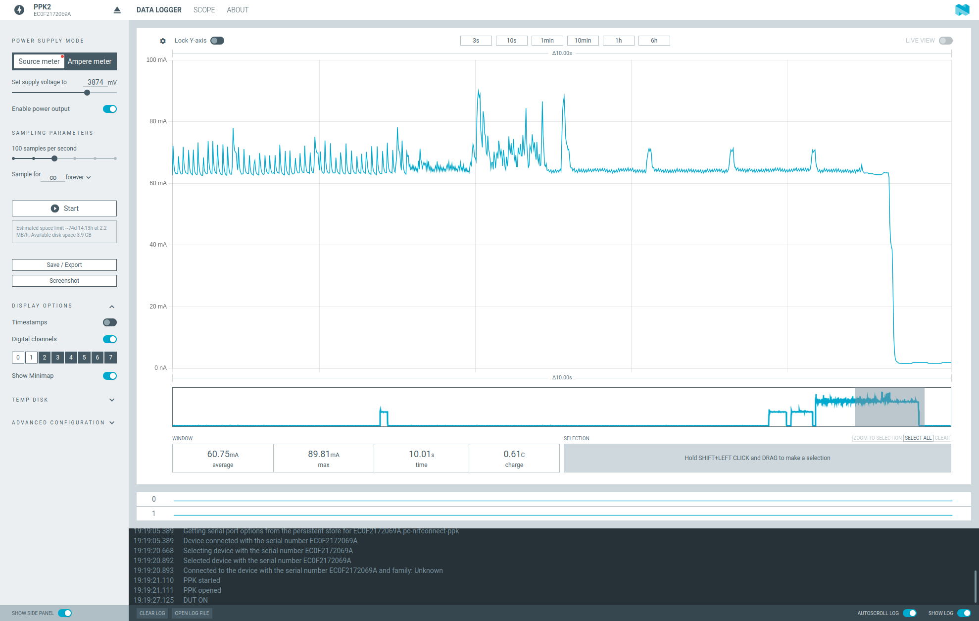
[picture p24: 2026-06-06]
firmware/power_measurements/ble_typewrt_receiving_files.png

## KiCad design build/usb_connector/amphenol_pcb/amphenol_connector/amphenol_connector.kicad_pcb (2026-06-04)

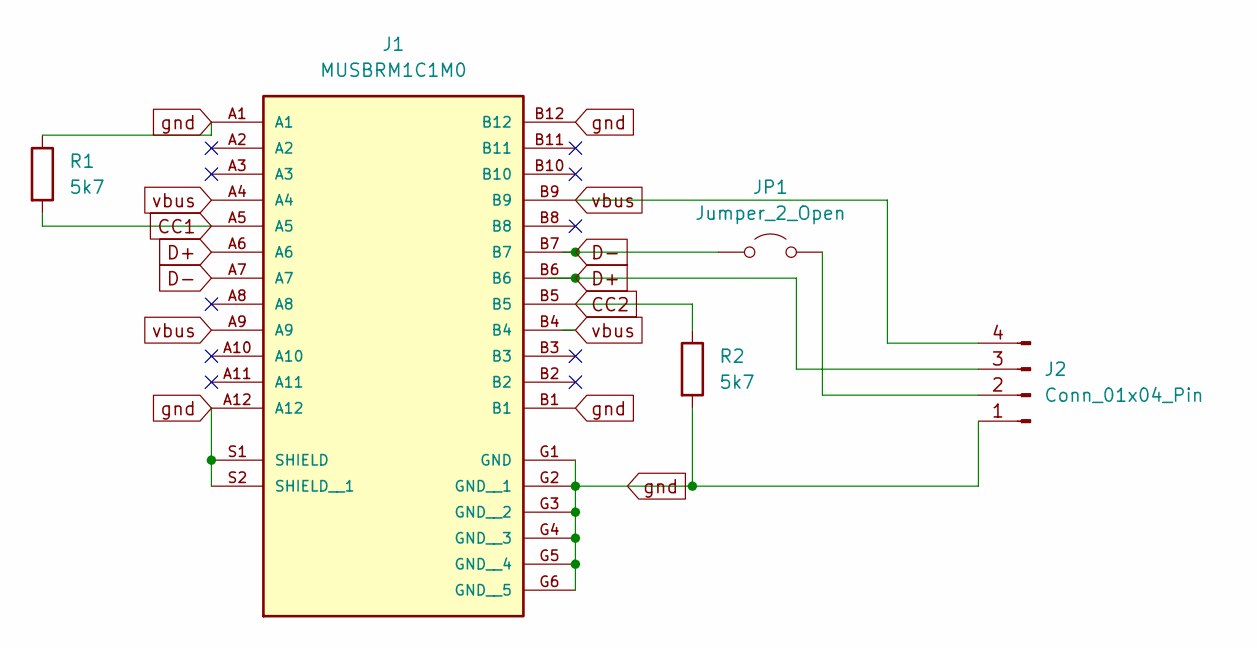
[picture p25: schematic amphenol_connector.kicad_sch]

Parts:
J1: MUSBRM1C1M0; AMPHENOL_MUSBRM1C1M0_no_courtyard; PARTREV D
J2: Conn_01x04_Pin; PinHeader_1x04_P1.27mm_Vertical
JP1: Jumper_2_Open; PinHeader_1x02_P1.27mm_Vertical
R1, R2: 5k7; R_1206_3216Metric_Pad1.30x1.75mm_HandSolder

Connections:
CC1: J1.A5, R1.2
CC2: J1.B5, R2.1
D+: J1.A6, J1.B6, J2.3
D-: J1.A7, J1.B7, JP1.1 (A)
unnamed: J2.2, JP1.2 (B)
gnd: J1.A1, J1.A12, J1.B1, J1.B12, J1.G1 (GND), J1.G2 (GND__1), J1.G3 (GND__2), J1.G4 (GND__3), J1.G5 (GND__4), J1.G6 (GND__5), J1.S1 (SHIELD), J1.S2 (SHIELD__1), J2.1, R1.1, R2.2
vbus: J1.A4, J1.A9, J1.B4, J1.B9, J2.4

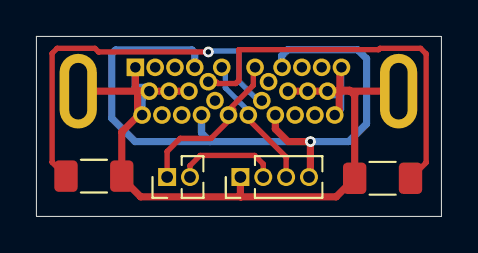
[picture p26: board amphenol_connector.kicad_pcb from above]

Board: 2 copper layers, 22.5 x 10.0 mm, 5 parts (0 on the bottom side), 7 nets.

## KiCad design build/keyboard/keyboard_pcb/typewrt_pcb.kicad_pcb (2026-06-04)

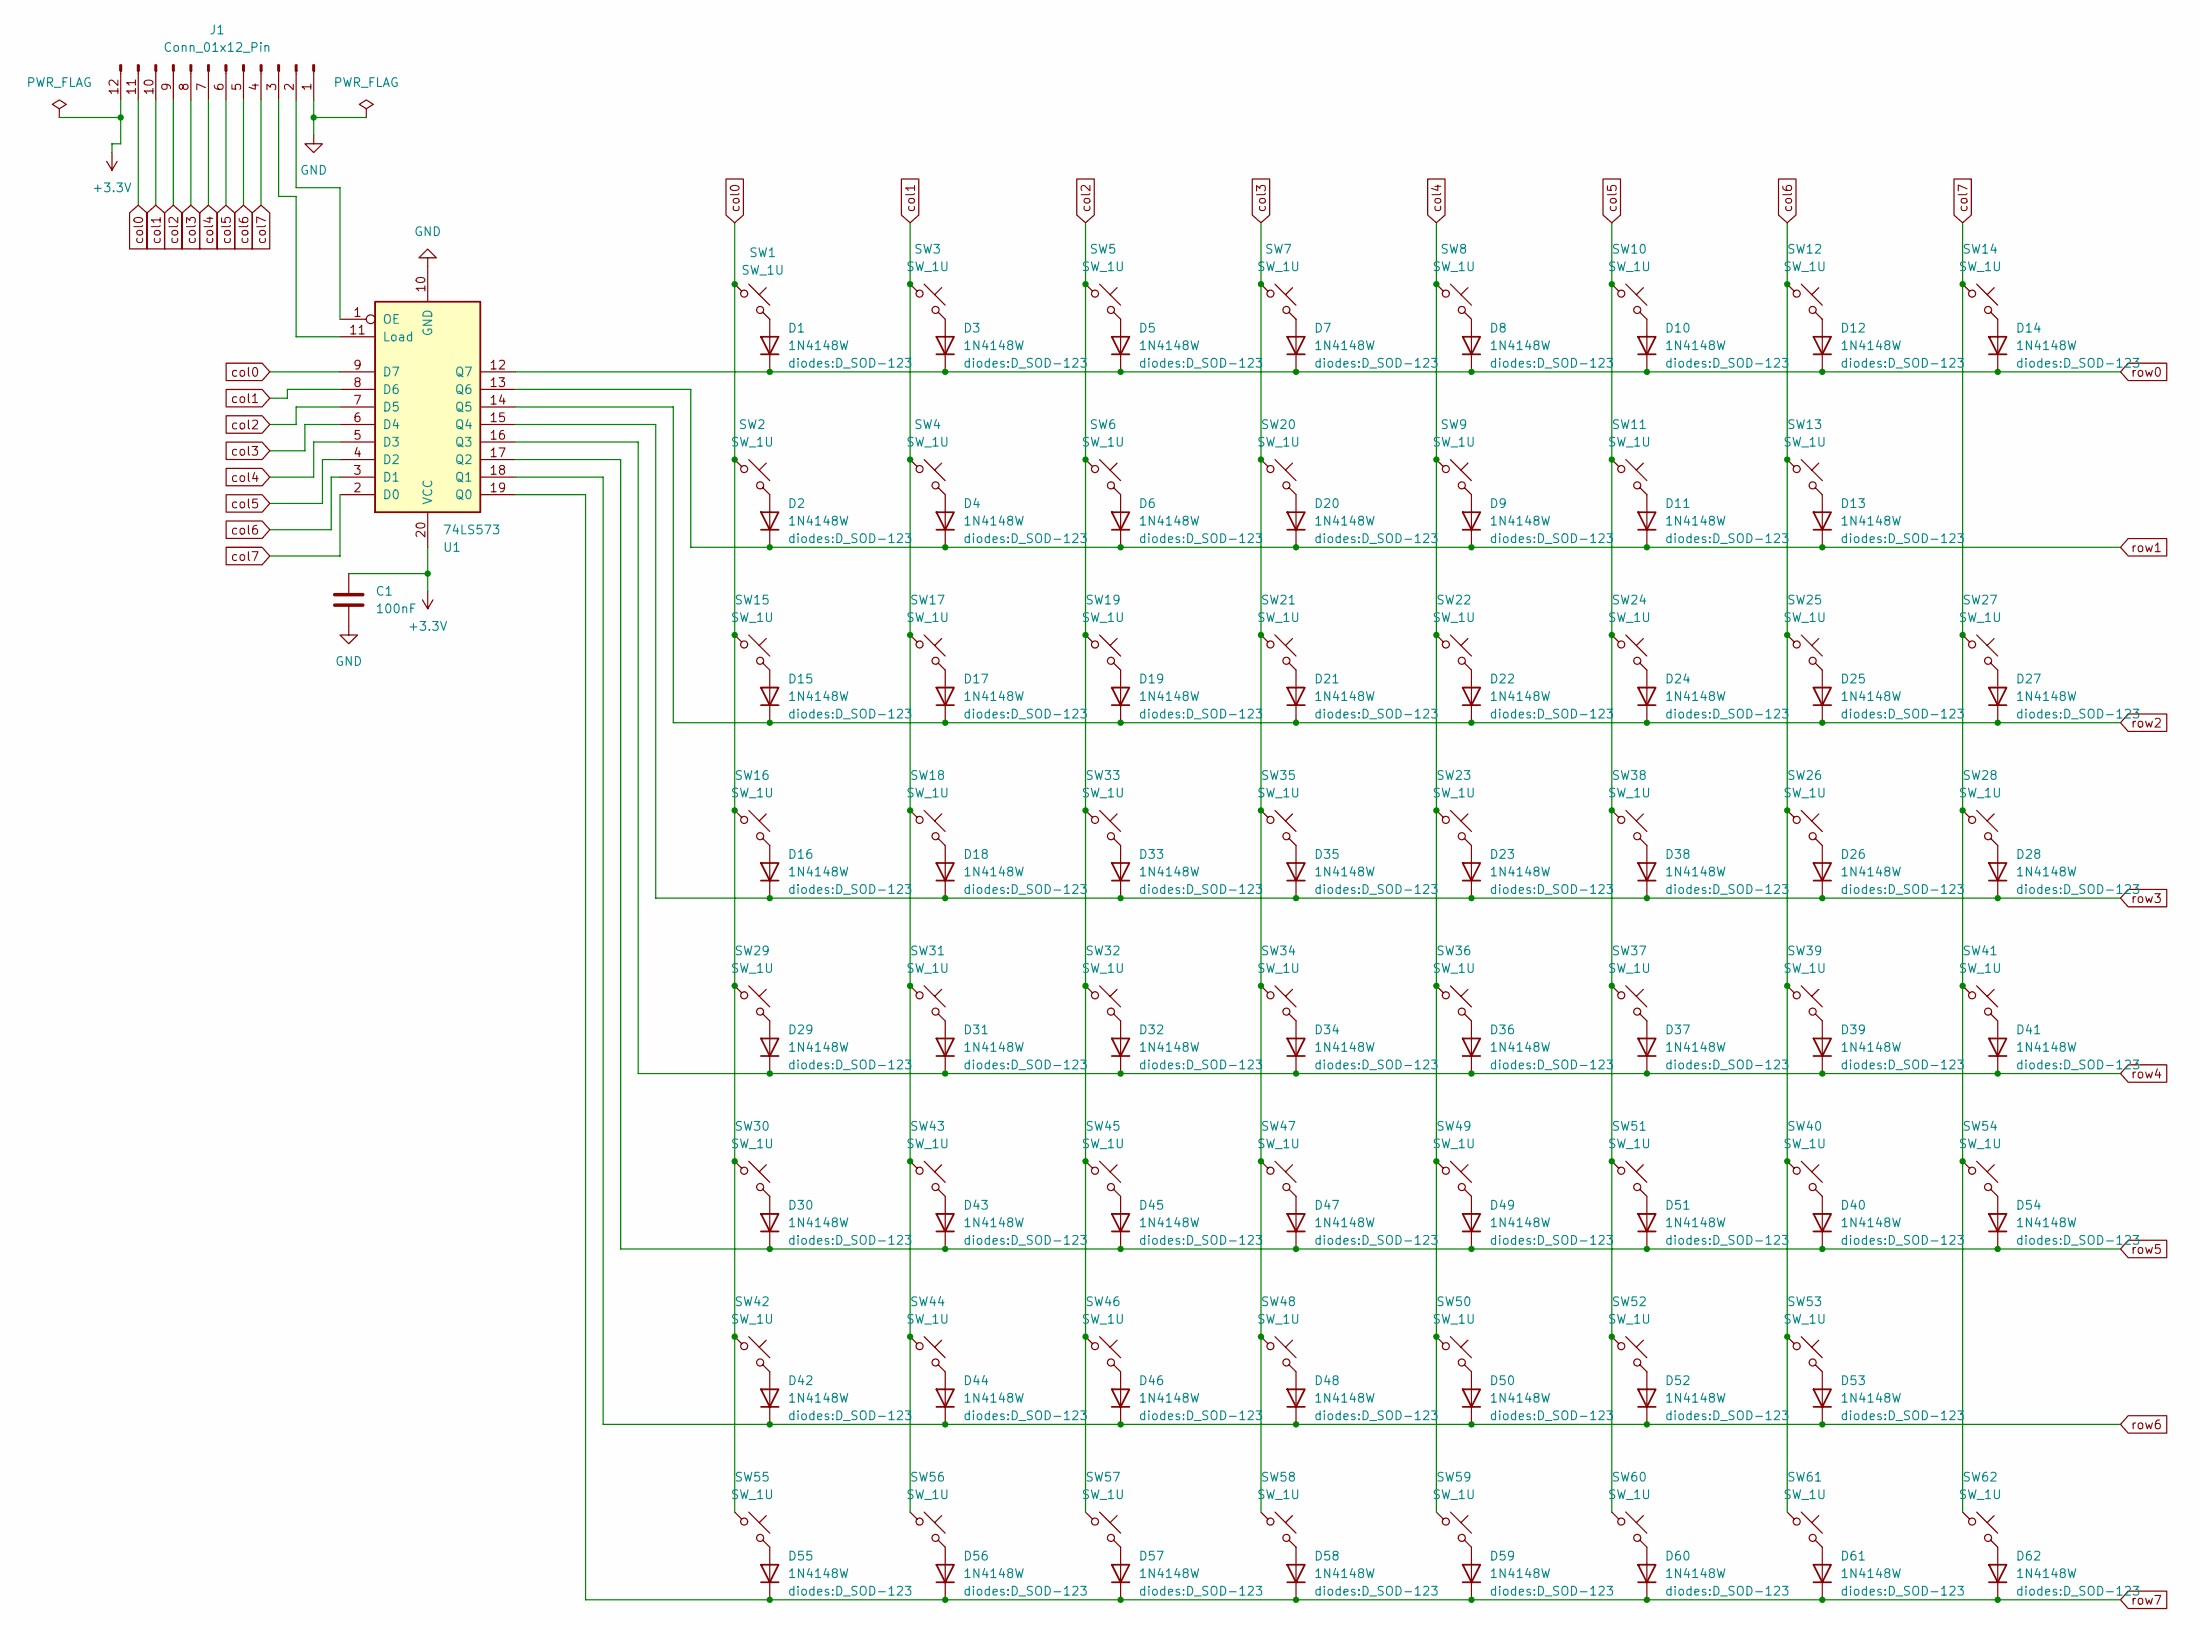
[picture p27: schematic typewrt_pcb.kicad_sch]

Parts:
C1: 100nF; C_1206_3216Metric_Pad1.33x1.80mm_HandSolder
D1, D2, D3, D4, D5, D6, D7, D8, D9, D10, D11, D12, D13, D14, D15, D16, D17, D18, D19, D20, D21, D22, D23, D24, D25, D26, D27, D28, D29, D30, D31, D32, D33, D34, D35, D36, D37, D38, D39, D40, D41, D42, D43, D44, D45, D46, D47, D48, D49, D50, D51, D52, D53, D54, D55, D56, D57, D58, D59, D60, D61, D62: 1N4148W; D_SOD-123
J1: Conn_01x12_Pin; PinHeader_1x12_P1.27mm_Vertical
SW1, SW2, SW3, SW4, SW5, SW6, SW7, SW8, SW9, SW10, SW11, SW12, SW13, SW16, SW17, SW18, SW19, SW20, SW21, SW22, SW23, SW24, SW25, SW26, SW27, SW30, SW31, SW32, SW33, SW34, SW35, SW36, SW37, SW38, SW39, SW40, SW41, SW43, SW44, SW45, SW46, SW47, SW48, SW49, SW50, SW51, SW52, SW53: SW_1U; MX-Solderable-1U
SW14: SW_1U; MX-Solderable-2U
SW15: SW_1U; MX-Solderable-1.5U
SW28: SW_1U; MX-Solderable-ISO
SW29: SW_1U; MX-Solderable-1.75U
SW42, SW55, SW56, SW57, SW59, SW60, SW61, SW62: SW_1U; MX-Solderable-1.25U
SW54: SW_1U; MX-Solderable-2.75U
SW58: SW_1U; MX-Solderable-6.25U-ReversedStabilizers
U1: 74LS573; DIP-20_W7.62mm

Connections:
+3.3V: C1.1, J1.12, U1.20 (VCC)
GND: C1.2, J1.1, U1.10 (GND)
unnamed: D1.2 (A), SW1.2
unnamed: D2.2 (A), SW2.2
unnamed: D3.2 (A), SW3.2
unnamed: D4.2 (A), SW4.2
unnamed: D5.2 (A), SW5.2
unnamed: D6.2 (A), SW6.2
unnamed: D7.2 (A), SW7.2
unnamed: D8.2 (A), SW8.2
unnamed: D9.2 (A), SW9.2
unnamed: D10.2 (A), SW10.2
unnamed: D11.2 (A), SW11.2
unnamed: D12.2 (A), SW12.2
unnamed: D13.2 (A), SW13.2
unnamed: D14.2 (A), SW14.2
unnamed: D15.2 (A), SW15.2
unnamed: D16.2 (A), SW16.2
unnamed: D17.2 (A), SW17.2
unnamed: D18.2 (A), SW18.2
unnamed: D19.2 (A), SW19.2
unnamed: D20.2 (A), SW20.2
unnamed: D21.2 (A), SW21.2
unnamed: D22.2 (A), SW22.2
unnamed: D23.2 (A), SW23.2
unnamed: D24.2 (A), SW24.2
unnamed: D25.2 (A), SW25.2
unnamed: D26.2 (A), SW26.2
unnamed: D27.2 (A), SW27.2
unnamed: D28.2 (A), SW28.2
unnamed: D29.2 (A), SW29.2
unnamed: D30.2 (A), SW30.2
unnamed: D31.2 (A), SW31.2
unnamed: D32.2 (A), SW32.2
unnamed: D33.2 (A), SW33.2
unnamed: D34.2 (A), SW34.2
unnamed: D35.2 (A), SW35.2
unnamed: D36.2 (A), SW36.2
unnamed: D37.2 (A), SW37.2
unnamed: D38.2 (A), SW38.2
unnamed: D39.2 (A), SW39.2
unnamed: D40.2 (A), SW40.2
unnamed: D41.2 (A), SW41.2
unnamed: D42.2 (A), SW42.2
unnamed: D43.2 (A), SW43.2
unnamed: D44.2 (A), SW44.2
unnamed: D45.2 (A), SW45.2
unnamed: D46.2 (A), SW46.2
unnamed: D47.2 (A), SW47.2
unnamed: D48.2 (A), SW48.2
unnamed: D49.2 (A), SW49.2
unnamed: D50.2 (A), SW50.2
unnamed: D51.2 (A), SW51.2
unnamed: D52.2 (A), SW52.2
unnamed: D53.2 (A), SW53.2
unnamed: D54.2 (A), SW54.2
unnamed: D55.2 (A), SW55.2
unnamed: D56.2 (A), SW56.2
unnamed: D57.2 (A), SW57.2
unnamed: D58.2 (A), SW58.2
unnamed: D59.2 (A), SW59.2
unnamed: D60.2 (A), SW60.2
unnamed: D61.2 (A), SW61.2
unnamed: D62.2 (A), SW62.2
unnamed: J1.2, U1.1 (OE)
unnamed: J1.3, U1.11 (Load)
col0: J1.11, SW1.1, SW2.1, SW15.1, SW16.1, SW29.1, SW30.1, SW42.1, SW55.1, U1.9 (D7)
col1: J1.10, SW3.1, SW4.1, SW17.1, SW18.1, SW31.1, SW43.1, SW44.1, SW56.1, U1.8 (D6)
col2: J1.9, SW5.1, SW6.1, SW19.1, SW32.1, SW33.1, SW45.1, SW46.1, SW57.1, U1.7 (D5)
col3: J1.8, SW7.1, SW20.1, SW21.1, SW34.1, SW35.1, SW47.1, SW48.1, SW58.1, U1.6 (D4)
col4: J1.7, SW8.1, SW9.1, SW22.1, SW23.1, SW36.1, SW49.1, SW50.1, SW59.1, U1.5 (D3)
col5: J1.6, SW10.1, SW11.1, SW24.1, SW37.1, SW38.1, SW51.1, SW52.1, SW60.1, U1.4 (D2)
col6: J1.5, SW12.1, SW13.1, SW25.1, SW26.1, SW39.1, SW40.1, SW53.1, SW61.1, U1.3 (D1)
col7: J1.4, SW14.1, SW27.1, SW28.1, SW41.1, SW54.1, SW62.1, U1.2 (D0)
row0: D1.1 (K), D3.1 (K), D5.1 (K), D7.1 (K), D8.1 (K), D10.1 (K), D12.1 (K), D14.1 (K), U1.12 (Q7)
row1: D2.1 (K), D4.1 (K), D6.1 (K), D9.1 (K), D11.1 (K), D13.1 (K), D20.1 (K), U1.13 (Q6)
row2: D15.1 (K), D17.1 (K), D19.1 (K), D21.1 (K), D22.1 (K), D24.1 (K), D25.1 (K), D27.1 (K), U1.14 (Q5)
row3: D16.1 (K), D18.1 (K), D23.1 (K), D26.1 (K), D28.1 (K), D33.1 (K), D35.1 (K), D38.1 (K), U1.15 (Q4)
row4: D29.1 (K), D31.1 (K), D32.1 (K), D34.1 (K), D36.1 (K), D37.1 (K), D39.1 (K), D41.1 (K), U1.16 (Q3)
row5: D30.1 (K), D40.1 (K), D43.1 (K), D45.1 (K), D47.1 (K), D49.1 (K), D51.1 (K), D54.1 (K), U1.17 (Q2)
row6: D42.1 (K), D44.1 (K), D46.1 (K), D48.1 (K), D50.1 (K), D52.1 (K), D53.1 (K), U1.18 (Q1)
row7: D55.1 (K), D56.1 (K), D57.1 (K), D58.1 (K), D59.1 (K), D60.1 (K), D61.1 (K), D62.1 (K), U1.19 (Q0)

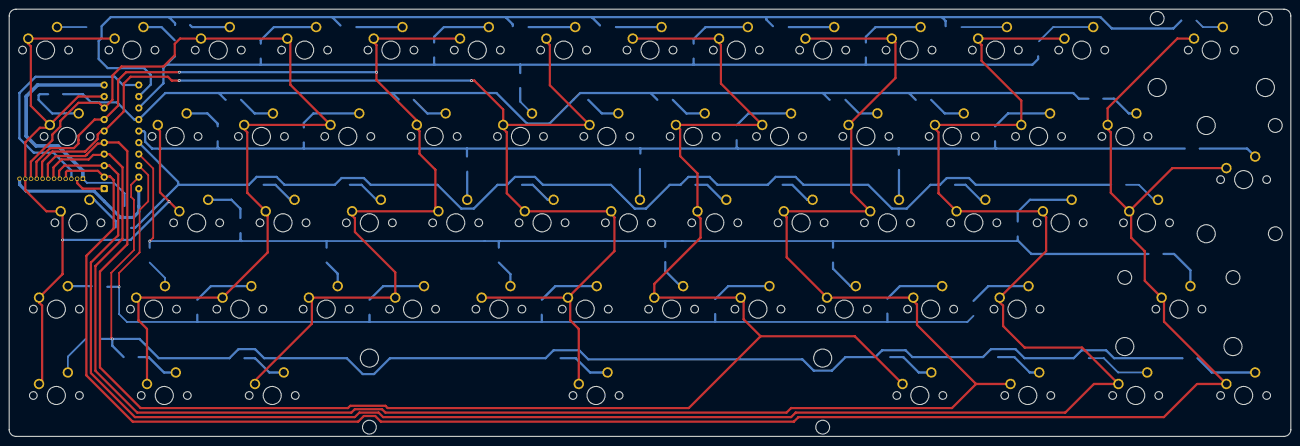
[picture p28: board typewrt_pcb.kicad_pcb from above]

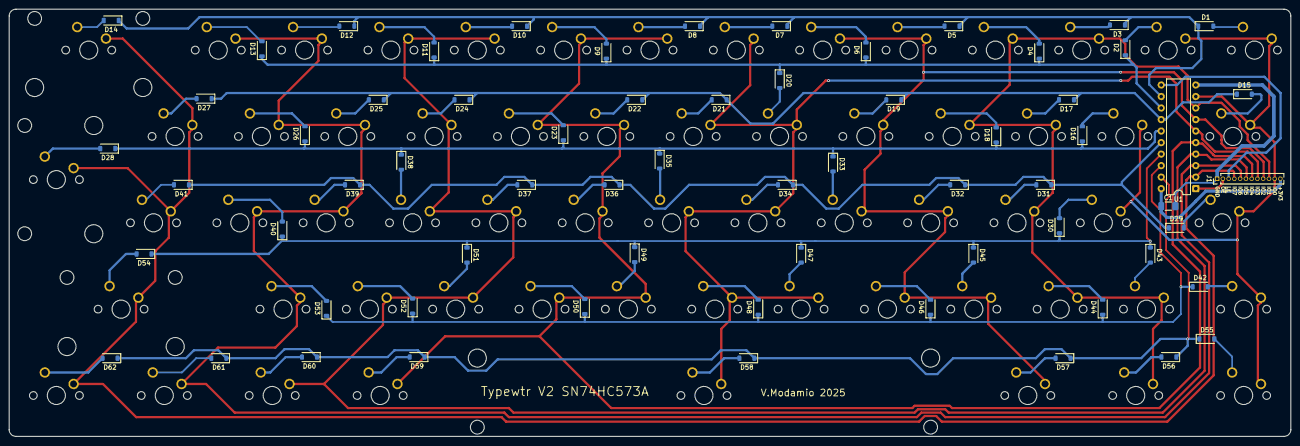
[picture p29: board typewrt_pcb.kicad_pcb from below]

Board: 2 copper layers, 282.8 x 94.2 mm, 127 parts (65 on the bottom side), 82 nets.

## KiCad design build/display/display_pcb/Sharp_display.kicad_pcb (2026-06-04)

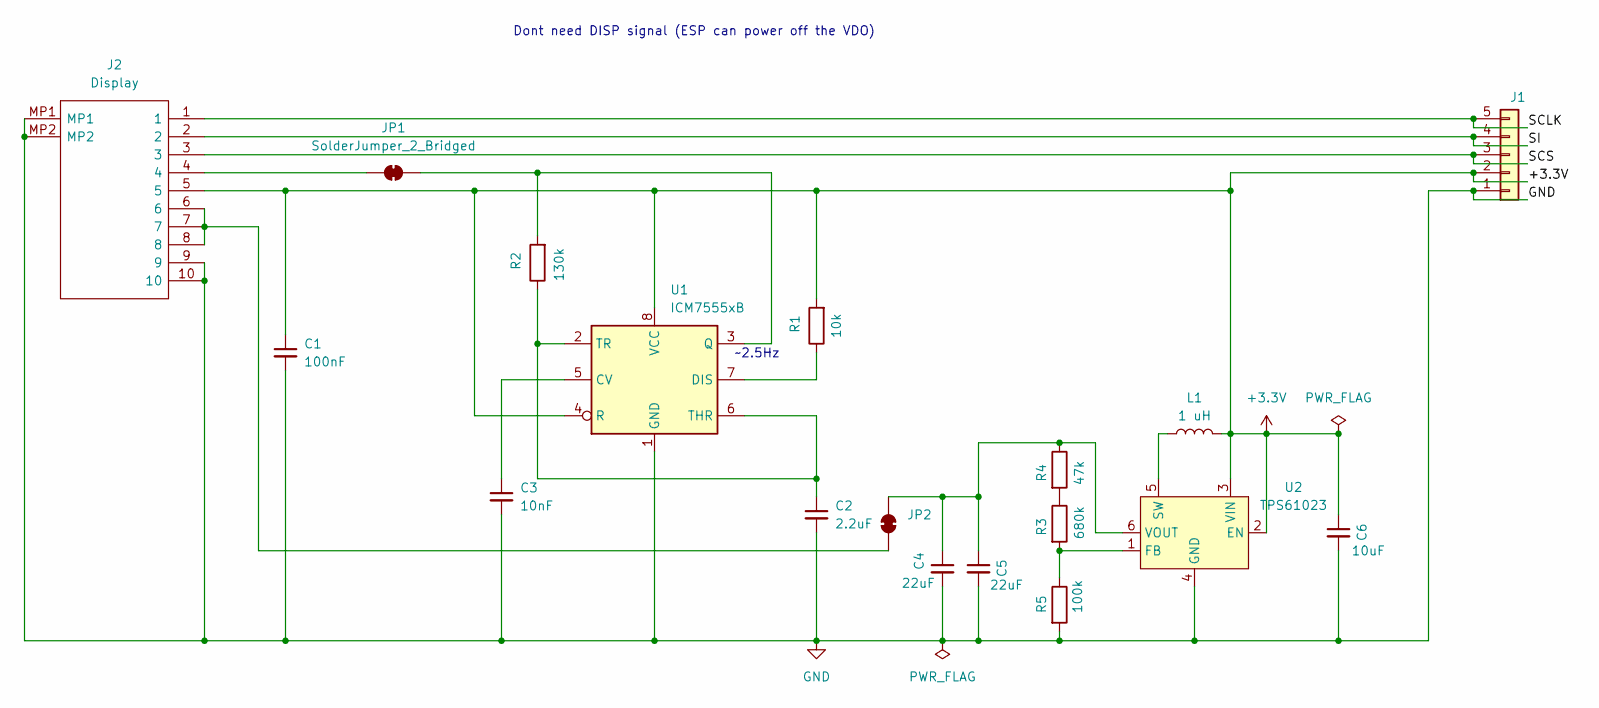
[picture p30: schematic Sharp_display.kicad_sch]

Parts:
C1: 100nF; C_1206_3216Metric_Pad1.33x1.80mm_HandSolder
C2: 2.2uF; C_1206_3216Metric_Pad1.33x1.80mm_HandSolder
C3: 10nF; C_1206_3216Metric_Pad1.33x1.80mm_HandSolder
C4, C5: 22uF; C_1206_3216Metric_Pad1.33x1.80mm_HandSolder
C6: 10uF; C_1206_3216Metric_Pad1.33x1.80mm_HandSolder
J1: Conn_01x05; PinHeader_1x05_P2.54mm_Vertical
J2: Display; GCT_FFC2B35-10-G_REVA2; Manufacturer_Part_Number 5051101092; Mouser Part Number N/A
JP1, JP2: SolderJumper_2_Bridged; SolderJumper-2_P1.3mm_Bridged2Bar_Pad1.0x1.5mm
L1: 1 uH; L_Wurth_WE-LQSH-4020
R1: 10k; R_1206_3216Metric_Pad1.30x1.75mm_HandSolder
R2: 130k; R_1206_3216Metric_Pad1.30x1.75mm_HandSolder
R3: 680k; R_1206_3216Metric_Pad1.30x1.75mm_HandSolder
R4: 47k; R_1206_3216Metric_Pad1.30x1.75mm_HandSolder
R5: 100k; R_1206_3216Metric_Pad1.30x1.75mm_HandSolder
U1: ICM7555xB; SOIC127P600X175-8N
U2: TPS61023; SOT-563

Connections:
+3.3V: C1.1, C6.1, J1.2, J2.5, L1.2, R1.2, U1.4 (R), U1.8 (VCC), U2.2 (EN), U2.3 (VIN)
/SCLK: J1.5, J2.1
/SCS: J1.3, J2.3
/SI: J1.4, J2.2
GND: C1.2, C2.2, C3.2, C4.2, C5.2, C6.2, J1.1, J2.9, J2.10, J2.MP1, J2.MP2, R5.2, U1.1 (GND), U2.4 (GND)
unnamed 5: J2.4, JP1.1 (A); also elsewhere on the board
unnamed: JP1.2 (B), R2.2, U1.3 (Q)
unnamed 7: J2.6, J2.7, J2.8, JP2.1 (A); also elsewhere on the board
unnamed: C4.1, C5.1, JP2.2 (B), R4.1, U2.6 (VOUT)
unnamed: R3.1, R4.2
unnamed: C3.1, U1.5 (CV)
unnamed: R1.1, U1.7 (DIS)
unnamed: C2.1, R2.1, U1.2 (TR), U1.6 (THR)
unnamed: R3.2, R5.1, U2.1 (FB)
unnamed: L1.1, U2.5 (SW)

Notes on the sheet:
~2.5Hz
Dont need DISP signal (ESP can power off the VDO)

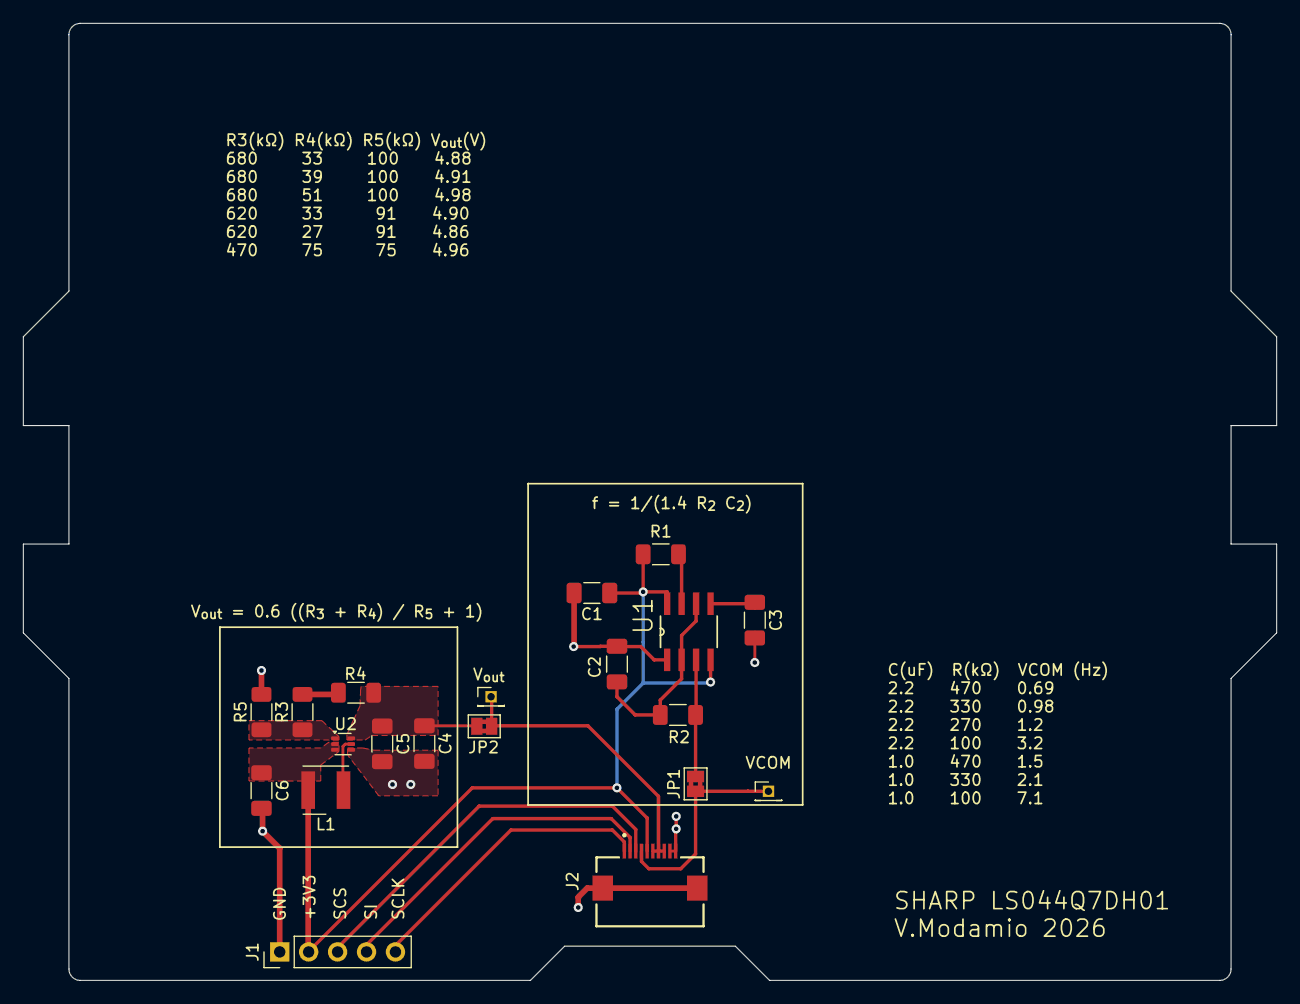
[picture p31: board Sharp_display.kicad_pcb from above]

Board: 2 copper layers, 110.0 x 84.0 mm, 20 parts (0 on the bottom side), 15 nets.

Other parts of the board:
VCOM: PinHeader_1x01_P1.27mm_Vertical
V_{out}: PinHeader_1x01_P1.27mm_Vertical

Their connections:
unnamed 5: VCOM.1; also elsewhere on the board
unnamed 7: V_{out}.1; also elsewhere on the board

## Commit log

2026-05-22 list of materials
2026-06-04 add pcbs plate
    [FFC2B35-10-G_REVA2.step, ICM7555IBAZ.step, MUSBRM1C1M0.step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]
2026-06-05 add enclosure
    [typewrt2_battery_carrier.stl, typewrt2_battery_head.stl, typewrt2_body_full.stl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]
2026-06-06 add power figures
